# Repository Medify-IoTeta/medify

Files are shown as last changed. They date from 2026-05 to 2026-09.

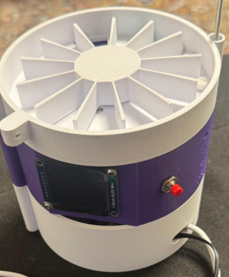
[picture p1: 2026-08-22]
docs/PillBox1.png

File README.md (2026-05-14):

# Medify — Smart Pill Box System

Medify is a smart medication intake system designed to help users manage and monitor their daily medication schedule. A physical smart pill box releases medication at scheduled times, while a mobile app handles reminders, intake confirmation, and caregiver monitoring.

## System Overview

```
Smart Pill Box (Arduino) ──WiFi──► Backend (Spring Boot) ◄──REST──  Mobile App (Flutter)
                                          │
                                    PostgreSQL 15
```

### Components

| Component | Technology | Location |
|---|---|---|
| Mobile App | Flutter / Dart | `medify_app/` |
| Backend Server | Java 21 / Spring Boot 3.4 | `medify-backend/` |
| Smart Pill Box | C++ / Arduino | `medify-embedded/` |
| Documentation | | `docs/` |

## Key Features

- **Scheduled reminders** — notifications sent at Morning / Noon / Evening intake windows
- **Intake confirmation** — user approves via app, device physically releases medication
- **Intake tracking** — statuses: Pending, Approved, Taken, Missed, Skipped, Postponed
- **Caregiver monitoring** — family members can view intake history and receive missed-dose alerts
- **Simple UI** — designed for elderly and passive users

## Getting Started

### Prerequisites

- Java 21
- Maven
- Docker (for the database)
- Flutter SDK

### Run Locally

```bash
# 1. Start the database
cd medify-backend
docker-compose up -d

# 2. Start the backend
mvn spring-boot:run -pl app

# 3. Start the Flutter app (in a separate terminal)
cd medify_app
flutter run
```

## Documentation

- Backend: [`medify-backend/README.md`](medify-backend/README.md)
- Mobile App: [`medify_app/README.md`](medify_app/README.md)
- Product requirements: [`docs/project-overview.docx`](docs/project-overview.docx)

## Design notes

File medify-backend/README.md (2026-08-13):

# Medify Backend

Spring Boot backend server for the Medify smart pill box system. Handles medication schedules, intake tracking, notifications, and caregiver monitoring.

## Tech Stack

- Java 21
- Spring Boot 3.4.0
- PostgreSQL 15
- Flyway (database migrations)
- JPA / Hibernate
- Lombok
- Docker

## Architecture

Hexagonal (ports-and-adapters) Maven multi-module project:

```
app → api → domain
      ↓
     data → domain
```

| Module | Responsibility |
|---|---|
| `domain` | Business logic, models, port interfaces, schedulers |
| `data` | JPA repositories, Flyway migrations |
| `api` | REST controllers, services, NotificationAdapter |
| `app` | Spring Boot entry point |

## Getting Started

### Prerequisites

- Docker (recommended — runs Postgres + backend together)
- Java 21 and Maven (only needed if running the backend outside Docker)

### Run everything with Docker (recommended)

```bash
# Place your Firebase service-account key at medify-backend/secrets/firebase-service-account.json
# (git-ignored — ask a teammate or generate one in the Firebase console)

docker compose up --build
```

This starts Postgres and the backend together, wires the backend to Postgres via the
`postgres` service hostname, persists Postgres data in the `medify_data` volume, and
exposes the backend on `http://localhost:8080`. Config is driven by environment
variables — see `.env.example`. Health check: `GET /actuator/health`.

### Run the backend outside Docker

```bash
# Start only the database
docker compose up -d postgres

# Point the app at it and run
export DB_HOST=localhost
export FIREBASE_CREDENTIALS_PATH=./secrets/firebase-service-account.json
mvn spring-boot:run -pl app
```

The server starts on `http://localhost:8080`.

## API Reference

| Method | Endpoint | Description |
|---|---|---|
| GET | `/api/notification` | Poll for a pending notification |
| POST | `/api/notification` | Send user response (confirm / snooze / skip) |
| GET | `/api/medicines` | List all medicines |
| POST | `/api/medicines` | Register a new medicine |
| GET | `/api/intakes/today` | Today's intakes |
| PATCH | `/api/intakes/{id}/approve` | User approved intake |
| PATCH | `/api/intakes/{id}/released` | Device confirmed compartment emptied → TAKEN |
| PATCH | `/api/intakes/{id}/skip` | User skipped intake |
| PATCH | `/api/intakes/{id}/postpone` | User postponed intake |
| PATCH | `/api/intakes/{id}/missed` | Mark intake as MISSED |
| GET | `/api/notifications-log` | Notification history (`?userId=`) |

## Notification Flow

1. Scheduler fires at scheduled time (currently demo times: 22:05 / 22:10 / 22:30)
2. Creates one `Intake` record per timing window
3. Sends notification: `"Time to take your morning medicines"`
4. Frontend polls `GET /api/notification` and shows a dialog
5. User confirms → `approve` → device dispenses → `released` → intake marked as TAKEN

> To switch to production times (08:00 / 13:00 / 20:00), update the `@Scheduled` cron expressions in `ReminderScheduler.java`.

## Database

PostgreSQL 15 via Docker. Defaults below apply when no `.env` is provided; override any
of them with `DB_HOST` / `DB_PORT` / `DB_NAME` / `DB_USERNAME` / `DB_PASSWORD`.

| Setting | Default |
|---|---|
| Database | `medify` |
| User | `medify_user` |
| Password | `medify_pass` |
| Port | `5432` |

Schema is managed by Flyway. Migrations are in `data/src/main/resources/db/migration/`.

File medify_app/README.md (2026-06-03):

# Medify App

Flutter mobile application for the Medify smart pill box system. Serves both patients and caregivers.

## Tech Stack

- Flutter / Dart
- HTTP client (`package:http`)
- Google Fonts
- UUID

## Getting Started

### Prerequisites

- Flutter SDK
- Backend server running on `localhost:8080` (see [`medify-backend`](../medify-backend/README.md))

### Run

```bash
flutter run
```

## Screens

### Home Screen (Patient)
- Medication schedule grouped by intake window: Morning / Noon / Evening
- Each window is expandable to show medicines with dosage and instructions
- Progress indicator: how many windows completed today
- Notification polling every 3 seconds — shows a reminder dialog when it's time to take medication
- Dialog includes option to expand and see which medicines are in the window

### Caregiver Screen
- Summary card: windows completed today out of total scheduled
- Full medication schedule (always visible, grouped by window)
- Today's intake status per window (TAKEN / MISSED / PENDING / POSTPONED)
- Missed alerts log

### Register Screen
- Add a new medicine with name, dosage, timing window, and intake instructions

## Project Structure

```
lib/
├── main.dart
├── screens/
│   ├── home_screen.dart
│   ├── caregiver_screen.dart
│   └── register_screen.dart
├── models/
│   └── medicine.dart
├── services/
│   └── api_service.dart
├── widgets/
│   ├── medication_card.dart
│   ├── app_sidebar.dart
│   └── progress_ring.dart
└── theme/
    └── app_theme.dart
```

## Configuration

Backend URL is set in `lib/services/api_service.dart`:

```dart
// Switch between these two depending on target:
//static const String baseUrl = 'http://localhost:8080'; // browser / emulator
static const String baseUrl = 'http://192.168.7.17:8080'; // Android device (active)
static const String embeddedBaseUrl = 'http://192.168.7.18'; // pill box device
```

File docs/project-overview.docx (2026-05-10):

Project: Medify – smart pill box

Description:

The Medify system is a smart medication intake solution designed to manage and monitor medication intake for users who take multiple medications on a predefined schedule.

At scheduled intake times, the system automatically releases the medications into a dedicated intake compartment, based on user approval.
Medication intake is confirmed only after the intake compartment is emptied.

The system records intake times, provides reminders and alerts through a mobile application, and allows remote monitoring by family members or caregivers.

The goal of the system is to reduce medication intake errors while providing a simple, reliable, and intuitive user experience, suitable also for passive users.

Use cases:

1. Medication guidance and intake monitoring:

A user wants to know when medication should be taken and to track whether it was taken.

When it is time to take medication, the system sends a reminder through the mobile application.

After the user approves the intake, the system automatically releases the medication into a dedicated intake compartment.

The system records the intake time only after the intake compartment is emptied and updates the medication status in the application.

2. Intake confirmation and handling of incomplete intake:

A user may not complete the medication intake after medications were released.
The system monitors whether the intake compartment was emptied within a predefined time window.

If the intake compartment is not emptied, the system marks the intake as incomplete and sends a notification to the user.
When required, the system also updates family members or caregivers about the incomplete intake.

3. Monitoring by family members or caregivers:

A family member or caregiver wants to monitor the medication intake of a patient who has difficulty managing it independently.
The application allows viewing the medication status and receiving alerts for taken, missed, postponed, skipped, or incomplete intakes.

Requirements:

1. Medication dispensing and intake confirmation:

The system should dispense medication at the scheduled time by releasing it into a dedicated intake compartment, and confirm the intake only after the intake compartment is emptied.

2. User guidance:

The system should notify the user when it is time to take medication, according to the predefined schedule, through a mobile notification and an on-device screen indication.

3. Intake time recording:

The system should record medication intake times and present the status of each intake in the mobile application, based on confirmed intake after the intake compartment is emptied.

4. Alerts and updates:

The system should notify the user in cases of deviations from the medication intake process, such as missed, skipped, or incomplete intakes, and allow updates to be shared with family members or caregivers when required.

5. Remote monitoring:

The application should allow family members or caregivers to monitor the user’s medication intake status.

6. Ease of use:

The application should be designed to be simple and intuitive, with a clear interface suitable for users who have difficulty using complex applications, such as elderly users.

7. Reliability:

The system should operate reliably and provide consistent and accurate information about medication intake.

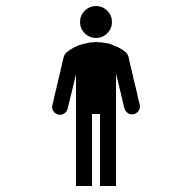
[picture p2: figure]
Man with solid fill
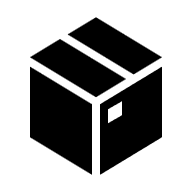
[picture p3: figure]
Box with solid fill
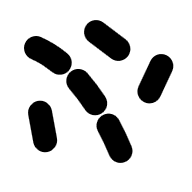
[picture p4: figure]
Germ with solid fill
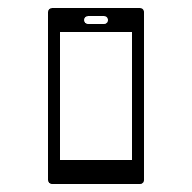
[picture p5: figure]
Smart Phone with solid fill
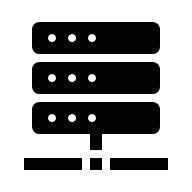
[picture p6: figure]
Server with solid fill
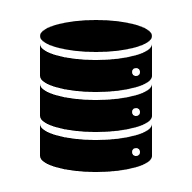
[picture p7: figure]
Database with solid fill

System Architecture:

User

Smart pill box

Mobile application

Backend server

Database

WIFI

Internet (REST API)

Modules:

1. Smart Pill Box Module (Device)

The Smart Pill Box module is responsible for the physical execution of medication intake and for reliable reporting of intake status to the system.

- Medication Release Mechanism Releases medication into the intake compartment according to the predefined schedule, after user confirmation either via a physical button press on the device or through the mobile application during the intake window.
- Intake Compartment Monitoring Monitors the intake compartment to detect whether the medication was taken, based on the compartment state (empty / not empty).
- Local User Indication Provides on-device guidance to the user using local indicators such as LEDs or a display, signaling when medication should be taken.
- Network Communication Communicates with the backend server over Wi-Fi using a REST API to report intake status and receive configuration updates.
- Autonomous Operation Operates independently of the mobile application and continues functioning even when the user’s phone is not nearby.

2. Mobile Application Module

The Mobile Application module serves as the primary user interface for patients, family members, and caregivers, enabling monitoring, notifications, and interaction with the system.

- Medication Schedule Visualization Displays the medication schedule and the status of each intake window, including taken, missed, postponed, or incomplete intakes.
- Notifications and Reminders Sends reminders to the user when an intake window begins and alerts in cases of deviations from the expected intake process.
- Intake Status Monitoring Retrieves intake status updates from the backend server and presents real-time or historical intake information.
- Intake Postponement (Snooze) Allows the user to postpone an intake window and receive a follow-up reminder after a predefined delay.
- Caregiver and Family View Enables authorized family members or caregivers to monitor medication intake status and receive relevant alerts.
- User Interaction Interface Provides a simple and intuitive interface designed to be accessible for elderly or passive users.

3. Backend Server Module

The Backend Server module functions as the central logic layer of the system, coordinating communication between the device, the mobile application, and the database.

- User and Role Management Manages users, including patients and authorized caregivers, and their associated permissions.
- Medication Schedule Management Stores and manages medication schedules and intake windows for each user.
- Intake Status Processing Receives intake status updates from the smart pill box, processes them, and determines the final intake state.
- Postponement Logic (Snooze Handling) Handles postponed intake windows and triggers follow-up reminders according to system rules.
- Notification and Alert Logic Determines when notifications should be sent to users and caregivers based on intake events or deviations.
- API Interface Exposes a REST API used by both the smart pill box and the mobile application for secure data exchange.

4. Database Module

The Database module is responsible for persistent and reliable storage of all system data, enabling long term tracking and monitoring.

- User Data Storage Stores user profiles, roles, and caregiver relationships.
- Medication and Schedule Storage Maintains information about medications and their associated intake schedules.
- Intake History Records Stores historical records of medication intake, including timestamps and intake status.
- Alert and Notification Logs Records notifications and alerts sent by the system for tracking and system monitoring purposes.
- Data Consistency and Reliability Ensures data integrity and supports recovery in case of system failures.

Technology Stack:

Smart Pill Box Device: Language: C++, Framework: Arduino.

Mobile: Language: Dart, Framework: Flutter.

Backend: Language: Java, Framework: Spring Boot.

Database: Language: SQL, Technology: PostgreSQL

API

Authentication Service:

- Endpoint: POST /auth/register Description: Creates a new user account (PATIENT or CAREGIVER). Request JSON: username, email, phone, password, type Response JSON: id, username, email, phone, type
- Endpoint: POST /auth/login

Description: Authenticates user credentials and returns an access token.

Request JSON: email, password

Response JSON: access_token, token_type, expires_in, user (id, username, email, phone, type)

- Endpoint: GET /users/me

Description: Returns the authenticated user profile information.

Request Headers: Authorization: Bearer <access_token>

Response JSON: id, username, email, phone, type

- Endpoint: PATCH /users/me/password

Description: Updates the authenticated user's password.

Request JSON: current_password, new_password

Response JSON: success

Caregiver Links API

- Endpoint: POST /caregiver-links

Description: Creates a caregiver link between a patient and a caregiver.

Request JSON: patient_id, caregiver_id, receive_alerts

Response JSON: patient_id, caregiver_id, receive_alerts

- Endpoint: GET /caregiver-links Description: Returns all caregiver links associated with the authenticated user (as patient or caregiver). Request Headers: Authorization: Bearer <access_token> Response JSON: items (array of: patient_id, caregiver_id, receive_alerts)
- Endpoint: PATCH /caregiver-links Description: Updates alert preference for an existing caregiver link. Request JSON: patient_id, caregiver_id, receive_alerts Response JSON: patient_id, caregiver_id, receive_alerts
- Endpoint: DELETE /caregiver-links Description: Removes an existing caregiver link between a patient and a caregiver. Request JSON: patient_id, caregiver_id Response JSON: success

Devices API

- Endpoint: POST /devices Description: Registers a new smart pill box device and assigns it to a patient. Request JSON: user_id, device_serial, device_name (optional)

Response JSON: id, user_id, device_serial, device_name, is_active, last_seen_time

- Endpoint: GET /devices Description: Returns all devices associated with the authenticated patient. Request Headers: Authorization: Bearer <access_token> Response JSON: items (array of: id, device_serial, device_name, is_active, last_seen_time)
- Endpoint: GET /devices/{id} Description: Returns detailed information about a specific device. Response JSON: id, user_id, device_serial, device_name, is_active, last_seen_time
- Endpoint: PATCH /devices/{id} Description: Updates device name or activation status. Request JSON: device_name (optional), is_active (optional) Response JSON: id, device_name, is_active
- Endpoint: PATCH /devices/{id}/heartbeat Description: Updates the device last communication time to indicate that the device is online. Request JSON: (empty) Response JSON: id, last_seen_time

Medications API

- Endpoint: POST /medications Description: Creates a new medication for the authenticated patient, including optional pre-intake reminder rules. Request Headers: Authorization: Bearer <access_token> Request JSON: name, description (optional), pre_intake_notice_minutes (optional), pre_intake_notice_text (optional), is_active Response JSON: id, user_id, name, description, pre_intake_notice_minutes, pre_intake_notice_text, is_active
- Endpoint: GET /medications

Description: Returns all medications for the authenticated patient.

Request Headers: Authorization: Bearer <access_token>

Response JSON: items (array of: id, name, description, pre_intake_notice_minutes, pre_intake_notice_text, is_active)

- Endpoint: GET /medications/{id} Description: Returns a specific medication by id. Request Headers: Authorization: Bearer <access_token> Response JSON: id, user_id, name, description, pre_intake_notice_minutes, pre_intake_notice_text, is_active
- Endpoint: PATCH /medications/{id} Description: Updates medication fields and reminder rules for the authenticated patient. Request Headers: Authorization: Bearer <access_token> Request JSON: name (optional), description (optional), pre_intake_notice_minutes (optional), pre_intake_notice_text (optional), is_active (optional) Response JSON: id, user_id, name, description, pre_intake_notice_minutes, pre_intake_notice_text, is_active
- Endpoint: DELETE /medications/{id} Description: Deletes a medication by id for the authenticated patient. Request Headers: Authorization: Bearer <access_token> Response JSON: success

Intakes API

- Endpoint: GET /intakes Description: Returns intake windows for the authenticated patient within a requested time range. Request Headers: Authorization: Bearer <access_token> Request Query Params: from (datetime), to (datetime) Response JSON: items (array of: id, device_id, window_start_time, window_end_time, approved_time, released_time, emptied_time, status)
- Endpoint: GET /intakes/{id} Description: Returns a specific intake window occurrence by id. Request Headers: Authorization: Bearer <access_token> Response JSON: id, user_id, device_id, window_start_time, window_end_time, approved_time, released_time, emptied_time, status
- Endpoint: GET /intakes/today Description: Returns all intake windows for the authenticated patient for the current day. Request Headers: Authorization: Bearer <access_token> Response JSON: items (array of: id, device_id, window_start_time, window_end_time, approved_time, released_time, emptied_time, status)
- Endpoint: POST /intakes Description: Creates an intake window occurrence for a patient and device. Request JSON: user_id, device_id, window_start_time, window_end_time Response JSON: id, user_id, device_id, window_start_time, window_end_time, status
- Endpoint: PATCH /intakes/{id}/approve Description: Approves medication release for the intake window and stores the approval time. Request JSON: (empty) Response JSON: id, approved_time, status
- Endpoint: PATCH /intakes/{id}/released Description: Marks that medication was released into the intake compartment for this intake window. Request JSON: (empty) Response JSON: id, released_time, status
- Endpoint: PATCH /intakes/{id}/emptied Description: Marks that the intake compartment was detected as emptied and finalizes the intake status as TAKEN. Request JSON: (empty) Response JSON: id, emptied_time, status
- Endpoint: PATCH /intakes/{id}/skip Description: Skips the intake window and finalizes the status as SKIPPED. Request JSON: (empty) Response JSON: id, status
- Endpoint: PATCH /intakes/{id}/postpone Description: Postpones the intake window and finalizes the status as POSTPONED. Request JSON: (empty) Response JSON: id, status
- Endpoint: PATCH /intakes/{id}/missed Description: Marks the intake window as MISSED. Request Headers: Authorization: Bearer <access_token> Request JSON: (empty) Response JSON: id, status
- Endpoint: PATCH /intakes/{id}/incomplete

Description: Marks the intake window as INCOMPLETE.

Request Headers: Authorization: Bearer <access_token>

Request JSON: (empty)

Response JSON: id, status

Notifications Log API

- Endpoint: GET /notifications-log Description: Returns notification history for the authenticated user (patient or caregiver) within a requested time range. Request Headers: Authorization: Bearer <access_token> Request Query Params: from (datetime), to (datetime) Response JSON: items (array of: id, recipient_user_id, intake_id (nullable), type, message, sent_time, delivery_status (nullable))

DB Tables:

Users:

Purpose:
Stores all system users, including patients and caregivers, along with their identification and authentication details.

Columns:

- id (PK): Unique identifier for each user in the system.
- Username: Display name of the user.
- Email: User email address, used for authentication and notifications.
- Phone: User phone number, used for alerts and communication.
- Password_hash: Hashed password used for secure user authentication.
- Type: Defines the user role in the system (PATIENT or CAREGIVER).

Caregiver links:

Purpose:
Defines the association between patients and their caregivers or family members for monitoring and alerting purposes.

Columns:

- patient_id (FK → users.id) References the user who is the patient being monitored.
- caregiver_id (FK → users.id) References the user who acts as a caregiver or family member.
- receive_alerts Indicates whether the caregiver receives notifications about the patient’s medication intake status.

Intakes:

Purpose:
Stores each medication intake window occurrence and its final status, based on whether the intake compartment was emptied during the allowed time window.

This table represents the actual intake events performed by the user and is used for tracking, monitoring, and notifications.

Columns:

- id (PK): Unique identifier for each intake window occurrence, generated by the database.
- user_id (FK → users.id): References the patient associated with this intake.
- device_id (FK → devices.id): References the smart pill box device that handled the intake.
- window_start_time: Start time of the intake window.
- window_end_time: End time of the intake window.
- approved_time (nullable): Time when the user approved the medication release (via device button or mobile application).
- released_time (nullable): Time when the medication was released into the intake compartment.
- emptied_time (nullable): Time when the intake compartment was detected as emptied.
- Status: Final status of the intake window (e.g., TAKEN, INCOMPLETE, MISSED, SKIPPED, POSTPONED).

Devices:

Purpose:
Stores smart pill box devices registered in the system and links each device to its associated patient, enabling monitoring and communication between the device and the backend server.

Columns:

- id (PK): Unique identifier for each device in the system, generated by the database.
- user_id (FK → users.id): References the patient who owns/uses the device.
- device_serial: Unique device identifier (e.g., printed serial number) used for registration and identification.
- device_name (nullable): Optional user-friendly name for the device (e.g., “Living Room Pill Box”).
- is_active: Indicates whether the device is currently active/assigned.
- last_seen_time (nullable): The last time the backend received a communication/status update from the device.

Medications:

Purpose:
Stores the list of medications defined for each patient, including basic medication information and medication-specific reminder rules.

This table is used for schedule creation and for displaying medication details and related reminders in the mobile application.

Columns:

- id (PK): Unique identifier for each medication in the database.
- user_id (FK → users.id): References the patient to whom the medication belongs.
- Name: Medication name, as displayed in the mobile application.
- Description (nullable): Optional notes or instructions related to the medication (e.g., “take after food”, “take with water”).
- Pre_intake_notice_minutes (nullable): Number of minutes before the intake time to notify the user with a medication-related reminder.
- Pre_intake_notice_text (nullable): Text content of the medication-related reminder to be shown to the user (e.g., “Eat a meal before taking this medication”).
- Is_active: Indicates whether the medication is currently active for the patient.

Notifications log:

Purpose:
Stores a history of notifications and alerts sent by the system to patients and caregivers.
This table is used for monitoring, debugging, and tracking deviations from the expected intake process.

Columns:

- Id (PK): Unique identifier for each notification log entry, generated by the database.
- Recipient_user_id (FK → users.id): References the user who received the notification (patient or caregiver).
- Intake_id (FK → intakes.id, nullable): References the related intake window occurrence, if the notification is associated with a specific intake.
- Type: Notification type (WINDOW_REMINDER, PRE_INTAKE_REMINDER, MISSED_INTAKE, INCOMPLETE_INTAKE).
- Message: The content of the notification sent to the user.
- Sent_time: Timestamp indicating when the notification was sent.
- Delivery_status (nullable): Indicates whether the notification was delivered successfully (SENT, FAILED).

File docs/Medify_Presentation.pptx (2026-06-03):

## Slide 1

Medify

Smart Medication Management System

By Netta Spivak & Roy Tomer

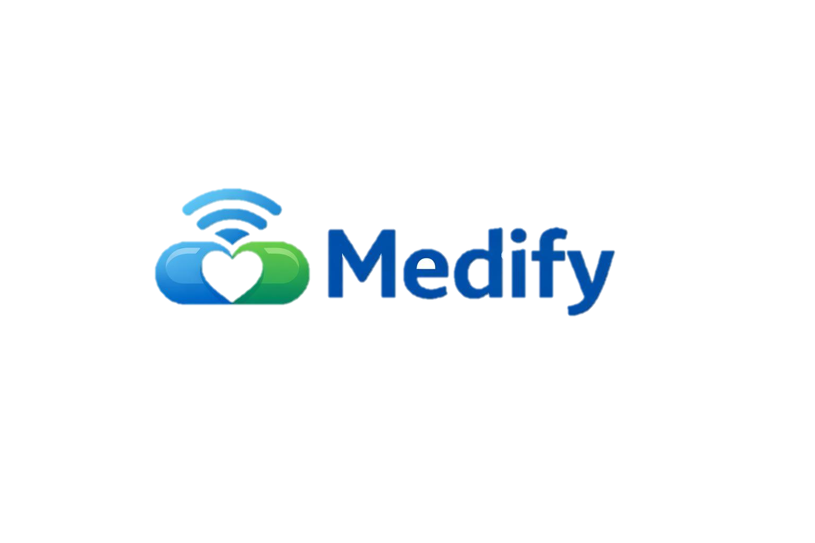
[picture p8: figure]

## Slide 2

The Problem

Why medication management is a critical challenge

- Patients taking multiple medications face high risk of missed or incorrect intake
- Passive solutions (pill organizers) provide no reminders or confirmation
- Complex apps are not suitable for elderly or cognitively impaired users
- Caregivers and family members have no visibility into daily intake compliance

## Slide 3

Our Solution

Bridging the gap between prescriptions and actual intake

From passive reminders to active medication management

Medify is a smart medication management system that combines a smart pill box with a mobile application to help patients take the right medication at the right time.
The system actively guides and monitors the medication intake process
from medication management, reminders and caregiver alerts to medication dispensing.

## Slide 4

Key Features

- Automatically dispenses medication at scheduled times after user approval.
- Using Sensor to identify when all of the medications were taken.

Smart Pill Box

- Real-time mobile reminders when an intake window opens.
- Intake approval via app or physical device button.
- Pre intake reminders.
- Caregiver view, for monitoring intake or missed intakes of the patient.

medication management

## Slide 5

System Architecture

Wi-Fi / REST

Smart Pill Box

Arduino / C++

Flutter App

Dart + Flutter

Wi-Fi / REST

REST API

Backend Server

Java + Spring Boot

Database

PostgreSQL 15

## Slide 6

Technology Stack

Choices and justifications

Backend

Java + Spring Boot

Java and Spring Boot provide a stable and proven environment for backend system development, with strong support for REST APIs, scheduling tasks, and database integration.

Frontend

Dart + Flutter

Flutter enables development of a single cross-platform application for both Android and iOS, while providing fast performance and a modern, responsive UI.

Hardware

Arduino / C++

Arduino and C++ provide a simple and accessible platform for embedded systems development, with extensive hardware library support and precise control over the device’s behavior.

Database

PostgreSQL

PostgreSQL provides reliable and consistent data management, while allowing easy schema management and smooth integration with Spring Boot.

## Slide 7

Domain — Smart Pill Box

Arduino / C++

Medication Release

Motor-driven mechanism releases medication into the intake compartment at scheduled times, after user approval

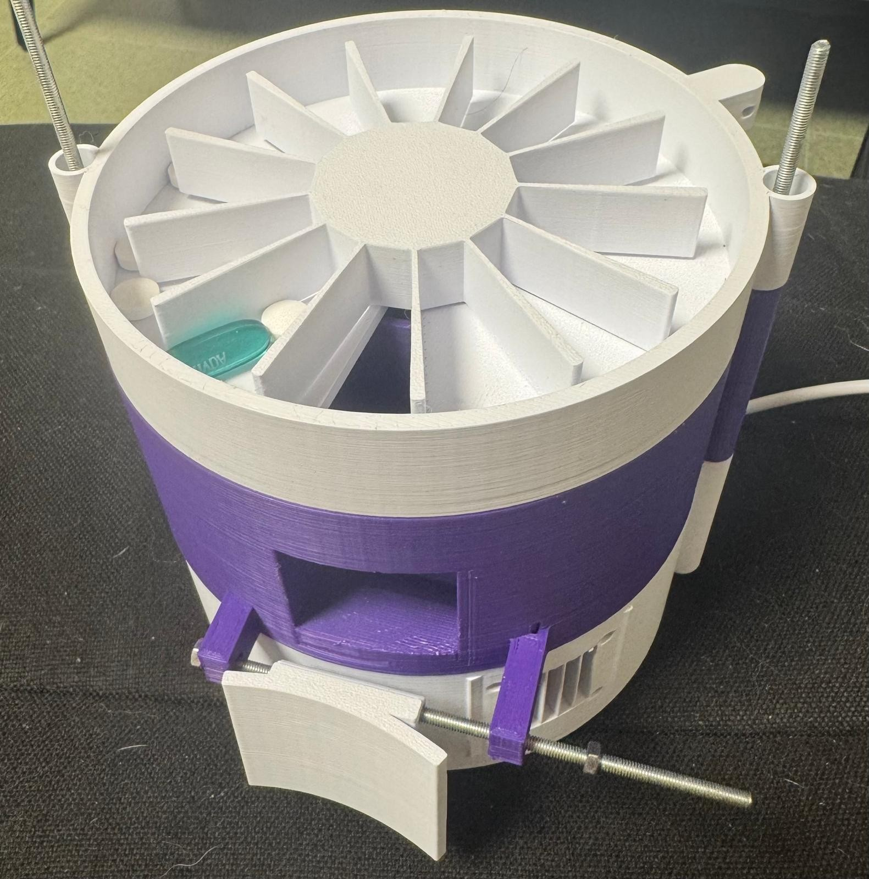
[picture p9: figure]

Compartment Monitoring

Sensor detects whether the intake compartment was emptied within the allowed time window

Medication Loading Guidance

LED indicators assist the user during medication setup by illuminating the correct compartments for each medication.

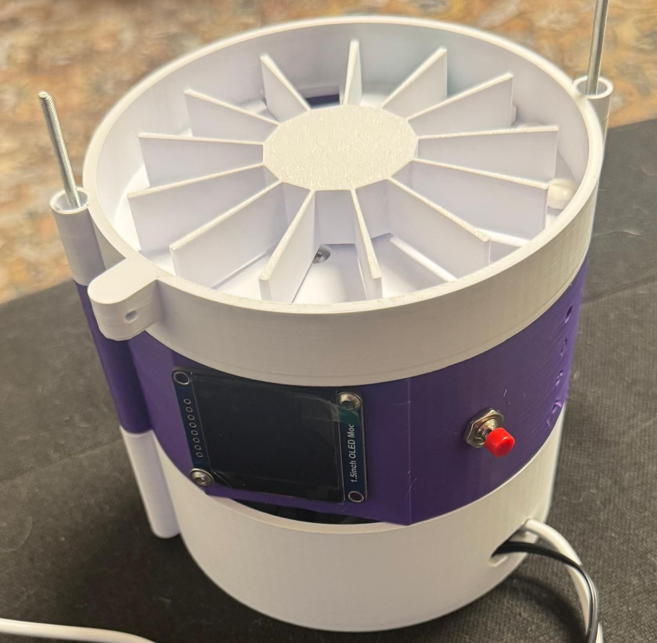
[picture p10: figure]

Autonomous Operation

Continues functioning independently even when the patient's phone is not nearby

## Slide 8

Domain — Mobile Application

Flutter + Dart

Medication Management

Users can manage their medications, define intake windows, and update their treatment routine directly through the app.

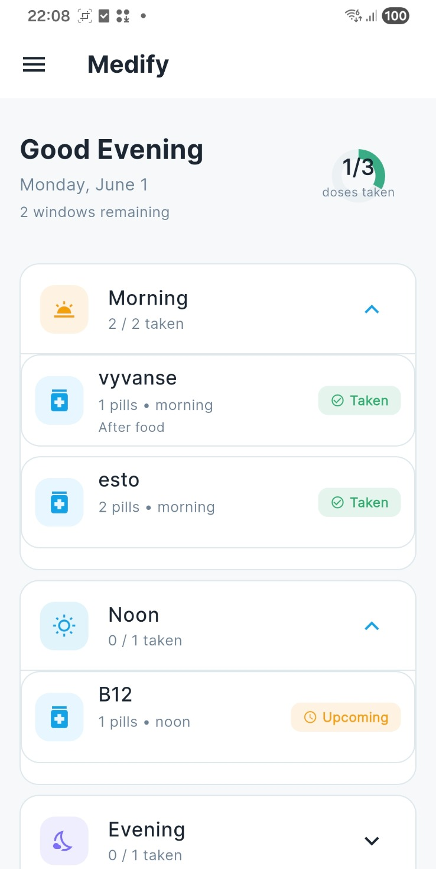
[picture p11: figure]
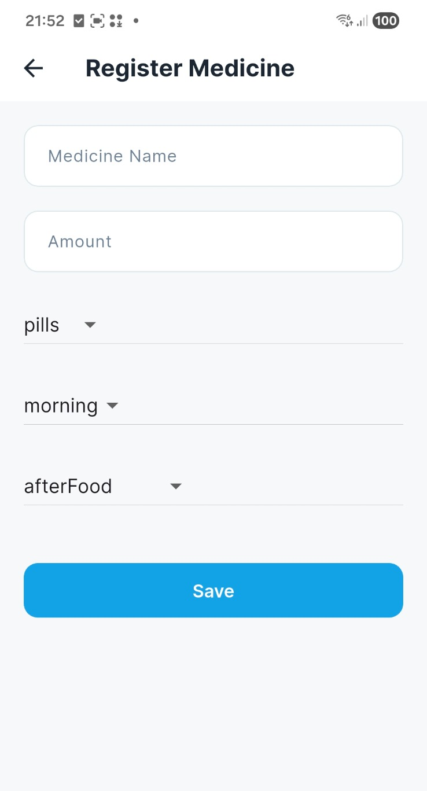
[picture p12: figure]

Accessible Experience

Simple UI designed to support elderly users.

Medication Setup

Guide users through the process of loading medications into the smart pill box.

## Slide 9

Domain — Mobile Application

Flutter + Dart

Notifications
& Reminders

Users receive reminders when an intake window opens, with the option to approve medication intake or snooze.

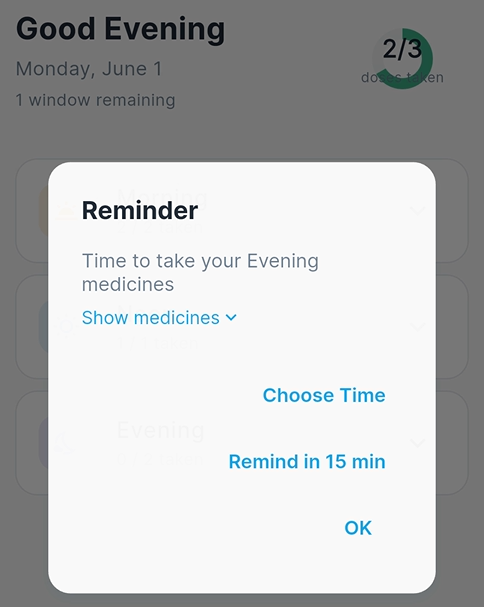
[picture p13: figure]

Caregiver View

Caregivers can monitor medication intake status in real time and receive alerts for missed or incomplete intakes.

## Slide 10

Domain — Backend Server

Java 21 · Spring Boot 3.4

Scheduling

Handles intake-related events based on predefined schedules.

Modules Structure

- app - Entry point.
- api - REST controllers, services.
- Domain - Business logic, schedulers, models.
- data - DB communication and access.

Intake Management

Manage the intake status lifecycle:
PENDING → APPROVED → TAKEN.

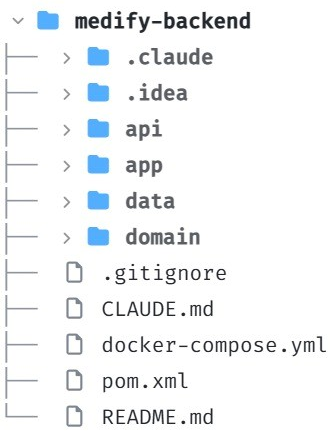
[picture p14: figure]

Data Management

Handles communication with the database.

Missed intake detection

Detects missed medication intake and sends alerts to caregivers.

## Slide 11

Domain — Database

PostgreSQL

users

User profiles, roles (PATIENT / CAREGIVER), authentication data

Medication name, timing window, dosage, pre-intake reminder rules

One record per timing window per day - tracks approval, release, and status

medications

intakes

caregiver_links

Patient-caregiver associations and alert preferences

notification_logs

History of all notifications and alerts sent by the system

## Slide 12

Current Project Status

Completed

- Patient app – register medications, schedule with intake window status, intake notification with approve or snooze options.
- Caregiver screen – intake schedule and daily status overview.
- Backend core - implement medication management, intake tracking, user and caregiver notifications and persistent DB storage.
- Automatic scheduling - Morning 08:00, Noon 13:00, Evening 20:00, and postpone an intake window.
- Arduino device - Wi-Fi communication, listen and response to API requests.
- Arduino device - app-controlled medication dispensing.
- PostgreSQL - database integration and schema management.

- Arduino device - detecting missed medication intake.
- Pill insertion flow - developing the process of inserting medications through the mobile application.
- Implementation of pre intake notifications.
- Multi-user support - extending the system to support multiple users and caregivers simultaneously.

Planned

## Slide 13

AI Usage in Development

- Lovable - used for visual planning and prototyping of the frontend screens before implementing them in Flutter.
- Claude Code - used for code generation, architecture discussions, debugging assistance, and project documentation.
- ChatGPT - used for document phrasing and assistance with planning the 3D printing components and OpenSCAD logic.

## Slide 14

System Demo

See Medify in action

▶

Video coming soon

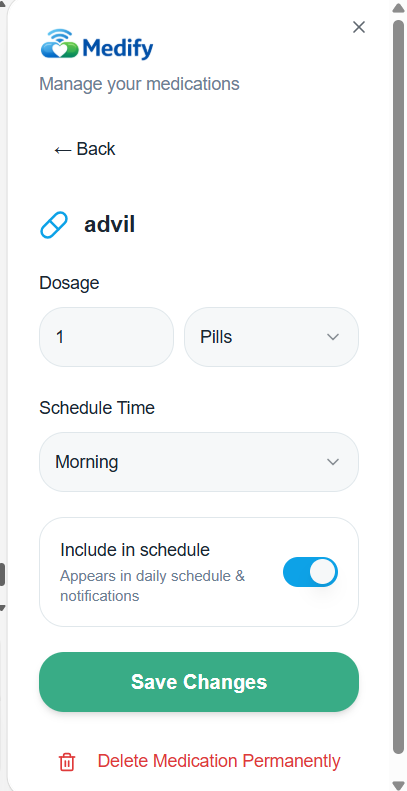
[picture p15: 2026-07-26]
docs/edit screen/Screenshot 2026-07-26 153617.png

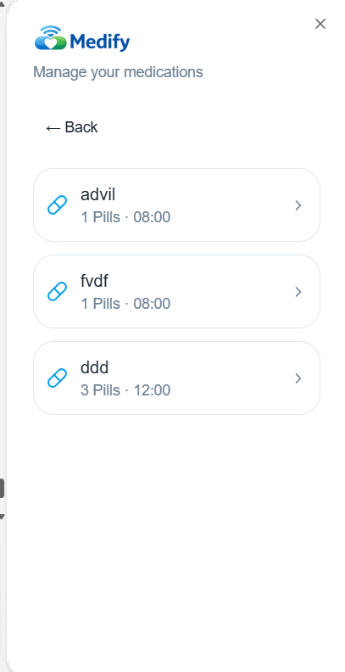
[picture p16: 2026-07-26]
docs/edit screen/Screenshot 2026-07-26 153655.png

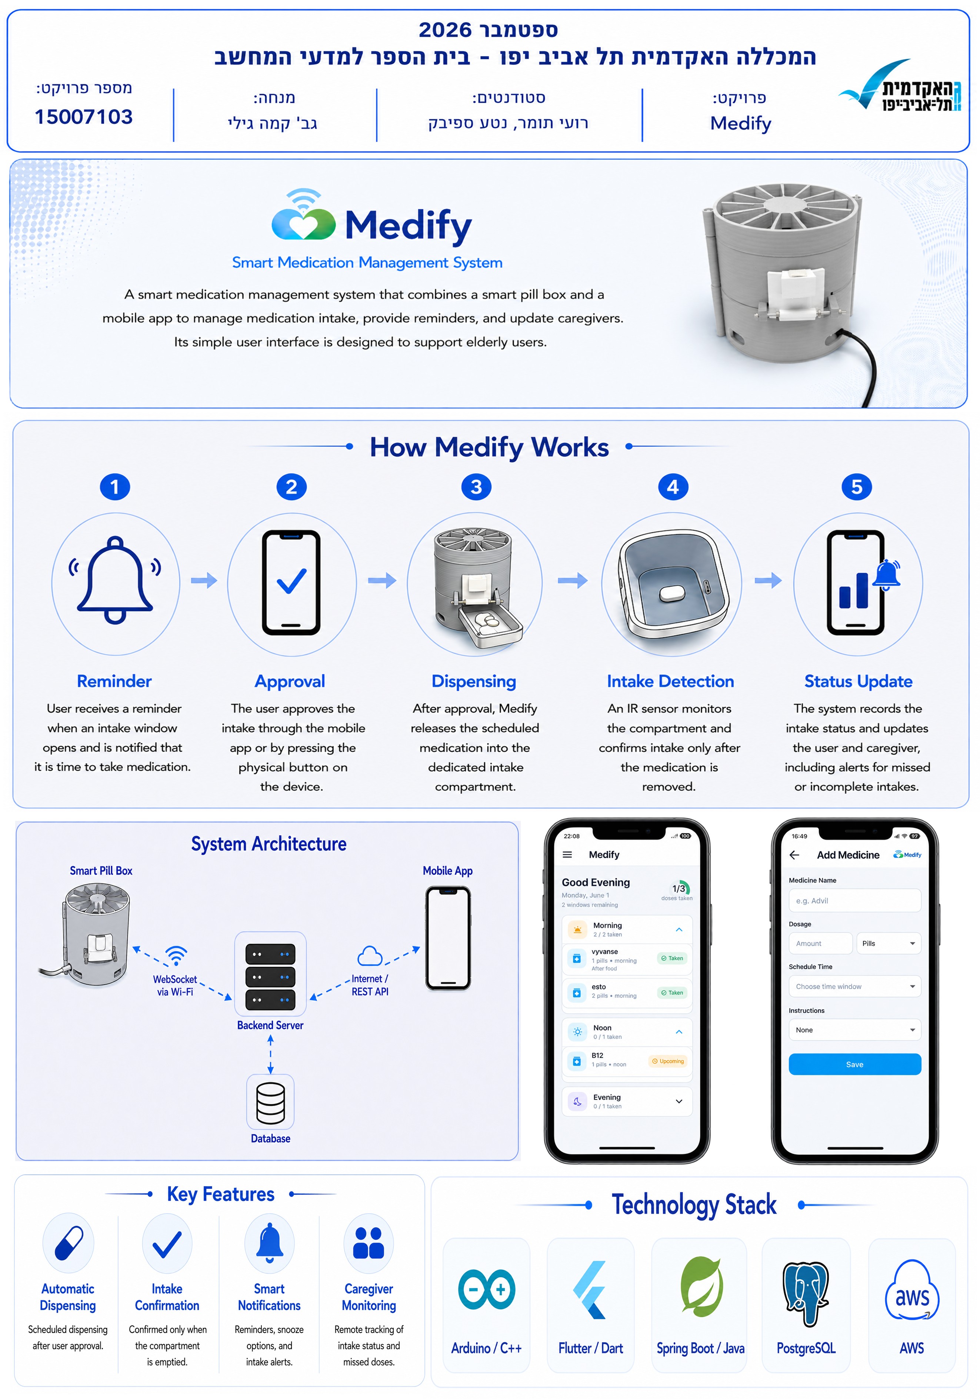
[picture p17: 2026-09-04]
docs/פוסטר.JPG

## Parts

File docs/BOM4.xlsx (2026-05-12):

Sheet: רכיבים
רכיבים
שם הרכיב | קישור | כמות | מחיר ליחידה | ספק | סטטוס | YES
Arduino Nano 33 IoT | קישור (https://www.4project.co.il/product/arduino-nano-33-iot-with-headers) | 1.00 | 150.30 | 4Project - 1 | בשימוש | YES
מטריצה - 400 נקודות | קישור (https://www.4project.co.il/product/breadboard-400-points-white) | 1.00 | 9.90 | 4Project - 1 | בשימוש | YES
מנוע צעד | קישור (https://www.4project.co.il/product/stepper-motor-28byj48-5v) | 1.00 | 14.80 | 4Project - 1 | בשימוש | YES
בקר למנוע צעד | קישור (https://hipertronics.co.il/product/%d7%9c%d7%95%d7%97-%d7%9c%d7%9e%d7%a0%d7%95%d7%a2-%d7%a6%d7%a2%d7%93-uln2003-%d7%9c%d7%90%d7%a8%d7%93%d7%95%d7%90%d7%99%d7%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) | 1.00 | 13.90 | היפרטרוניקס | בשימוש | YES
מסך OLED 0.91" | קישור (https://www.4project.co.il/product/oled-0.91inch-128x32-i2c-interface) | 1.00 | 37.80 | 4Project - 1 | טעות | YES
כפתור קטן | קישור (https://www.4project.co.il/product/panel-mount-button-red) | 1.00 | 2.90 | 4Project - 1 | לא הותקן | YES
מאוורר 25x25x10 | קישור (https://www.4project.co.il/product/540138) | 1.00 | 13.90 | 4Project - 1 | טעות | YES
כפתור גדול | קישור | 1.00 | 22.40 | 4Project - 1 | טעות | YES
ספק כוח 5V | קישור (https://www.4project.co.il/product/wall-adapter-power-supply-5v-2a) | 1.00 | 19.90 | 4Project - 1 | בשימוש | YES
רצועת לדים RGB | קישור (https://www.4project.co.il/product/addressable-rgb-60-led-strip-5v-1m-ws2812b) | 1.00 | 26.70 | 4Project - 3 | לא הותקן | YES
משדר IR קטן |  | 1.00 | 6.10 | 4Project - 1 | נהרס | YES
מקלט IR קטן |  | 1.00 | 6.10 | 4Project - 1 | נהרס | YES
מסך OLED 1.5" | קישור (https://www.4project.co.il/product/oled-1.5inch-128x128-i2c-spi-interface) | 1.00 | 78.20 | 4Project - 3 | לא הותקן | YES
מאוורר 10x30x30 |  | 1.00 | 13.70 | 4Project - 4 | לא הותקן | YES
מחבר שקע מתח | קישור (https://www.4project.co.il/product/334832) | 4.00 | 8.00 | 4Project - 1+ 2 | בשימוש | YES
IR Break Beam Sensor | קישור (https://www.dash.co.il/index.php?route=product/product&product_id=5375) | 1.00 | 80.00 | דאן אלקטרוניקה | לא הותקן | YES
 |  |  |  |  |  | NO
 |  |  |  |  |  | NO
 |  |  |  |  |  | NO
 |  |  |  |  |  | NO
 |  |  |  |  |  | NO
 |  |  |  |  |  | NO
 |  |  |  |  |  | NO
 |  |  |  |  |  | NO
 |  |  |  |  |  | NO
 |  |  |  |  |  | NO
 |  |  |  |  |  | NO
 |  |  |  |  |  | NO
 |  |  |  |  |  | NO
₪528.60 | סה"כ מחיר

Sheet: מוצרים נלווים
מוצרים נלווים
שם המוצר | לינק | שימוש | ספק | מחיר ליחידה | כמות יחידות | סטטוס | ספיירים | האם לחשב מחיר
נגד 100 אוהם | קישור (https://www.4project.co.il/product/resistor-100-ohm-5w-pth) |  | 4Project - 1 | 2.80 | 1.00 | לא בשימוש |  | YES
נגד 4.7 קילו אוהם |  |  | 4Project - 1 | 0.30 | 10.00 | לא בשימוש |  | YES
חוט זכר זכר 15 סנטימטר - 20 יחידות |  |  | 4Project - 1 | 18.80 | 2.00 | בשימוש חלקי |  | YES
חוט זכר נקבה 20 ס"מ - 40 יחידות |  |  | 4Project - 1 | 9.50 | 2.00 | בשימוש חלקי |  | YES
נגד 330 אוהם |  |  | 4Project - 2 | 0.30 | 10.00 | לא בשימוש |  | YES
קבל אלקטרוליטי 470 מיקרו |  |  | 4Project - 2 | 0.90 | 3.00 | לא בשימוש |  | YES
Esun PLA+ |  |  | ProMaker | 79.00 | 2.00 | בשימוש |  | YES
אום M3 |  |  | 4Project - 4 | 0.20 | 30.00 | בשימוש חלקי |  | YES
אום M3 ניילוק |  |  | 4Project - 4 | 0.25 | 10.00 | בשימוש חלקי |  | YES
דיסקית M3 שטוחה |  |  | 4Project - 4 | 0.07 | 40.00 | לא בשימוש |  | YES
בורג פיליפס ראש עגול mm10x2M |  |  | 4Project - 4 | 0.20 | 10.00 | לא בשימוש |  | YES
חוט פרימיום זכר זכר 12" - 10 יחידות | קישור (https://www.dash.co.il/index.php?product_id=1009387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) |  | דאן אלקטרוניקה | 32 | 1.00 | לא בשימוש |  | YES
חוט נקבה נקבה 6" - 20 יחידות | קישור (https://www.dash.co.il/index.php?route=product/product&product_id=1012796&search=JUMPER+WIRE+-+connected+6%22) |  | דאן אלקטרוניקה | 27.00 | 1.00 | לא בשימוש |  | YES
מוט הברגה M3 מגולוון 1 מטר | קישור (https://galboreg-shop.co.il/index.php?route=product/product&product_id=1049) |  | גלבורג | 7.08 | 5 | לא בשימוש |  | YES
אלן כפתור נירוסטה M3X10MM | קישור (https://galboreg-shop.co.il/index.php?route=product/product&product_id=19557) |  | גלבורג | 2.24 | 10 | לא בשימוש |  | YES
אלן כפתור נירוסטה M3X20MM | קישור (https://galboreg-shop.co.il/index.php?route=product/product&product_id=19562) |  | גלבורג | 3.54 | 10 | לא בשימוש |  | YES
 |  |  |  |  |  |  |  | NO
 |  |  |  |  |  |  |  | NO
 |  |  |  |  |  |  |  | NO
 |  |  |  |  |  |  |  | NO
 |  |  |  |  |  |  |  | NO
 |  |  |  |  |  |  |  | NO
 |  |  |  |  |  |  |  | NO
משלוח גלבורג |  |  | גלבורג | 38.00 | 1.00 |  |  | YES
אריזה ומשלוח 4Project |  |  | 4Project | 22.00 | 4.00 |  |  | YES
משלוח היפרטרוניקס |  |  | היפרטרוניקס | 50.00 | 1.00 |  |  | YES
משלוח ProMaker |  |  | ProMaker | 39.00 | 2.00 |  |  | YES
דמי טיפול גלבורג |  |  | גלבורג | 23.50 | 1.00 |  |  | YES
 |  |  |  |  |  |  |  | NO
₪669.10 | סה"כ מחיר

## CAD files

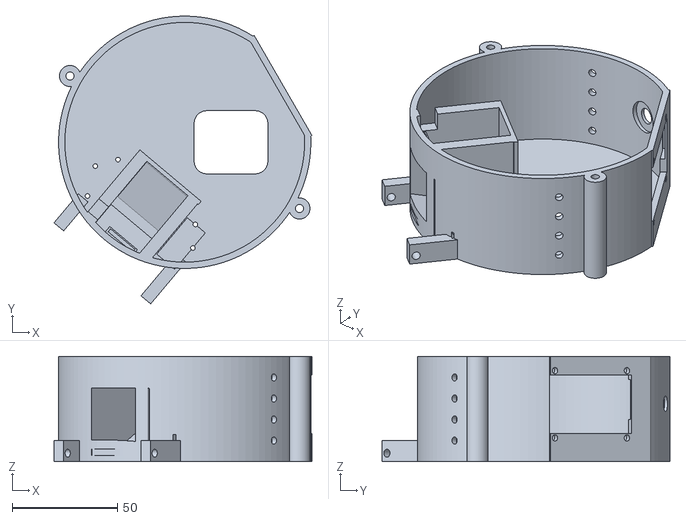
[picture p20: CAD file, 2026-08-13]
medify-embedded/Scad files/CurrentVersions/STL files/Floor1_6FINAL.stl
122.7 x 136.9 x 50.0

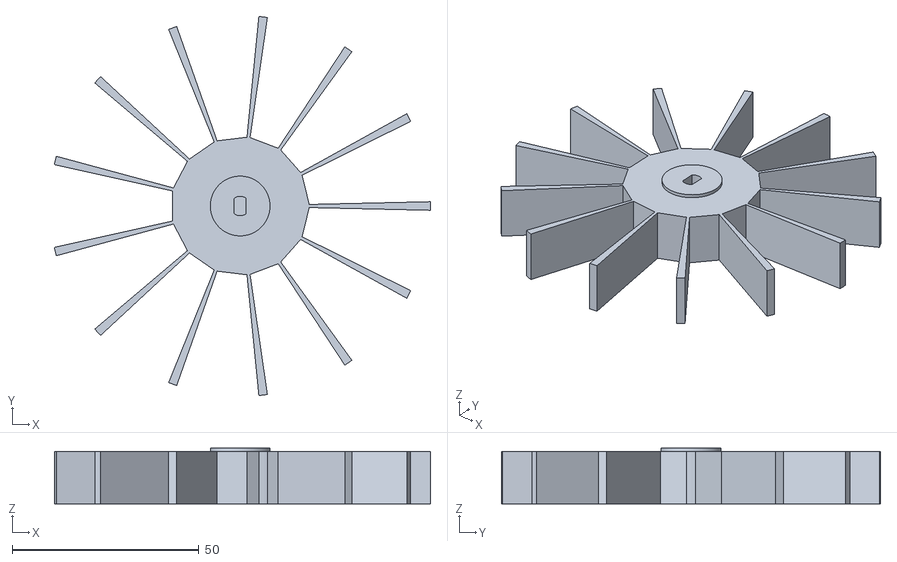
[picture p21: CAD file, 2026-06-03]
medify-embedded/Scad files/CurrentVersions/STL files/TempFourFloor2WindmillFINAL.stl
100.8 x 101.5 x 14.9

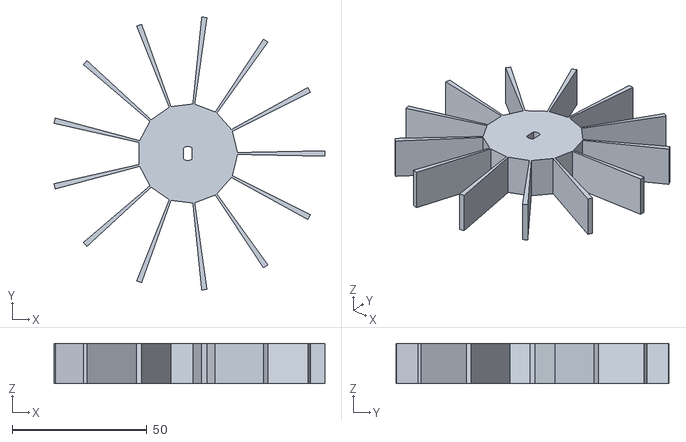
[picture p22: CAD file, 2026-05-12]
medify-embedded/Scad files/CurrentVersions/STL files/TempThreeFloor2WindmailFINAL.stl
100.7 x 101.4 x 15.0

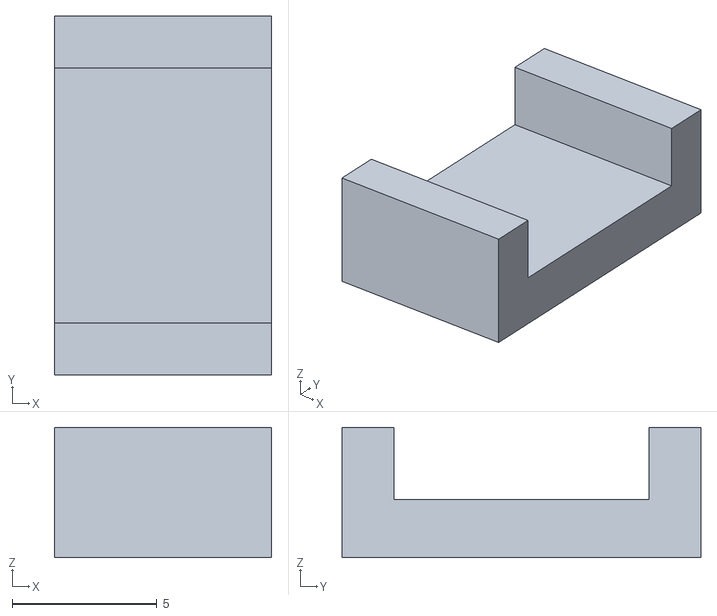
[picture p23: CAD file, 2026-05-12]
medify-embedded/Scad files/CurrentVersions/STL files/MagnetPocketCover3.stl
7.50 x 12.4 x 4.50

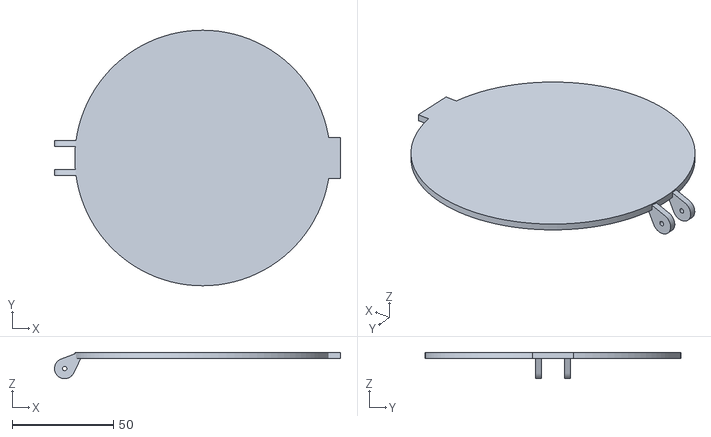
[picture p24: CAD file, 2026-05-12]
medify-embedded/Scad files/CurrentVersions/STL files/UpperCover.stl
141.0 x 126.0 x 13.0

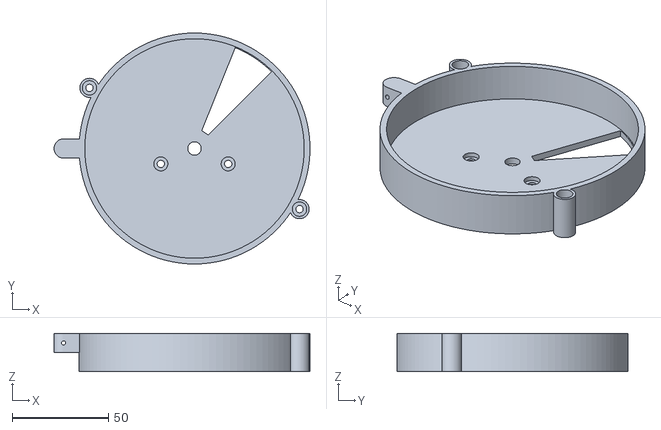
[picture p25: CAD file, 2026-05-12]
medify-embedded/Scad files/CurrentVersions/STL files/Floor2Base5FINALREAL.stl
133.0 x 120.0 x 20.0

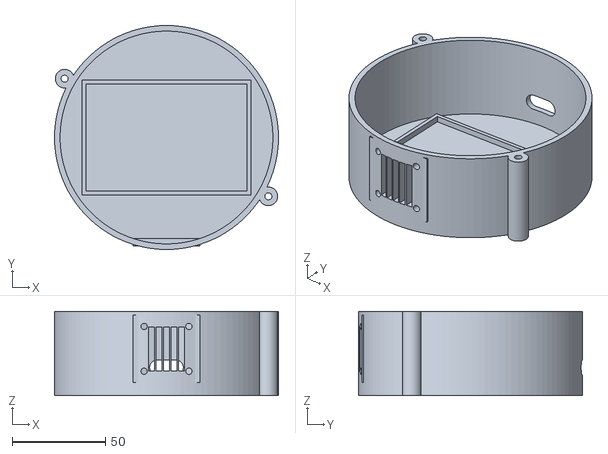
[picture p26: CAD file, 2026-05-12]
medify-embedded/Scad files/CurrentVersions/STL files/Floor0NEW.stl
120.0 x 120.0 x 45.0

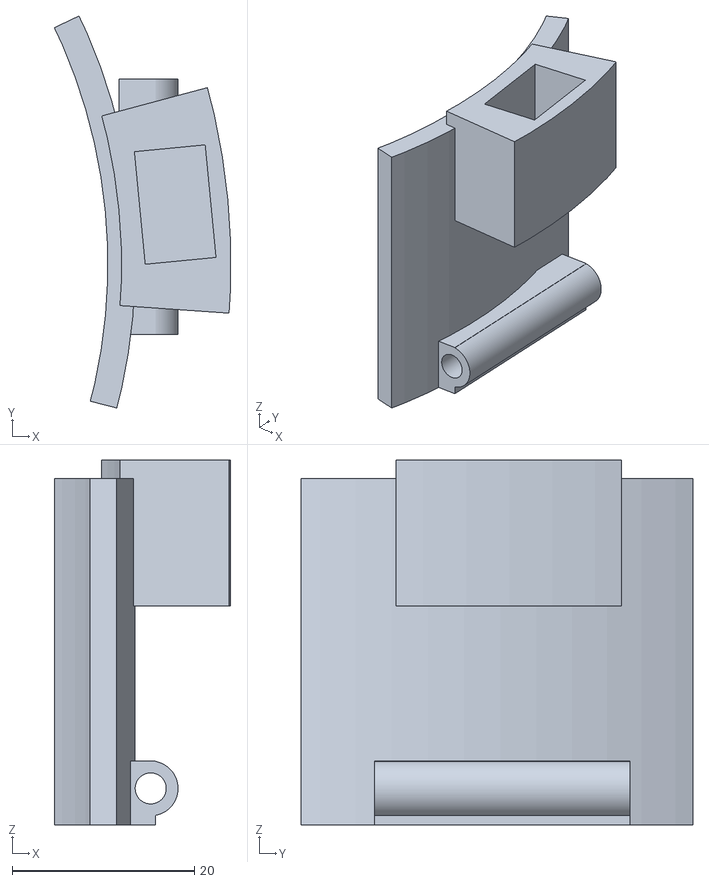
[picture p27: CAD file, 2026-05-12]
medify-embedded/Scad files/CurrentVersions/STL files/TempDoor.stl
19.3 x 43.0 x 40.0

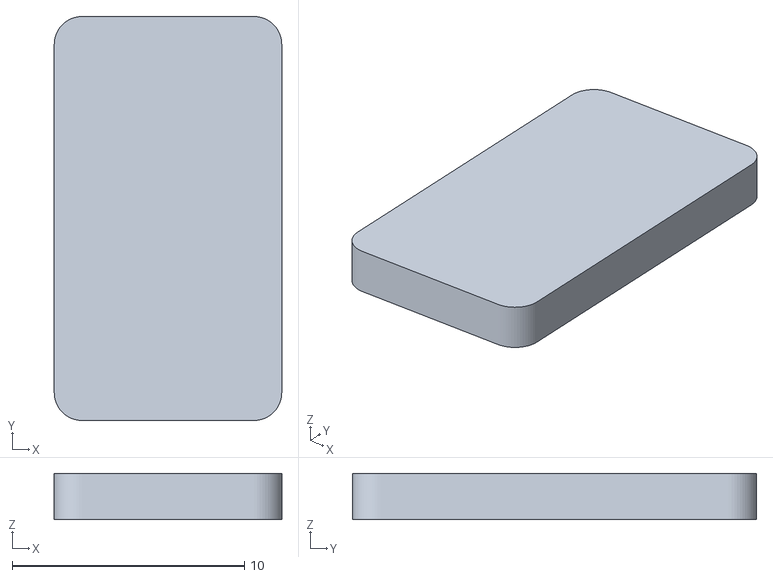
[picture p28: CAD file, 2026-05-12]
medify-embedded/Scad files/CurrentVersions/STL files/MagnetPocketCover1.stl
9.80 x 17.4 x 2.00

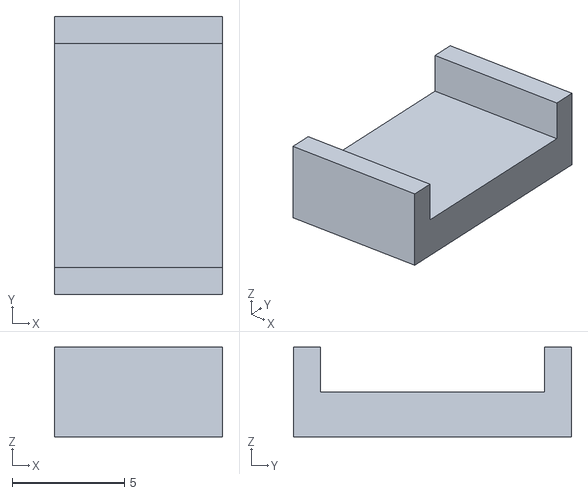
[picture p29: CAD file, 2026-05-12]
medify-embedded/Scad files/CurrentVersions/STL files/MagnetPocketCover2.stl
7.50 x 12.4 x 4.00

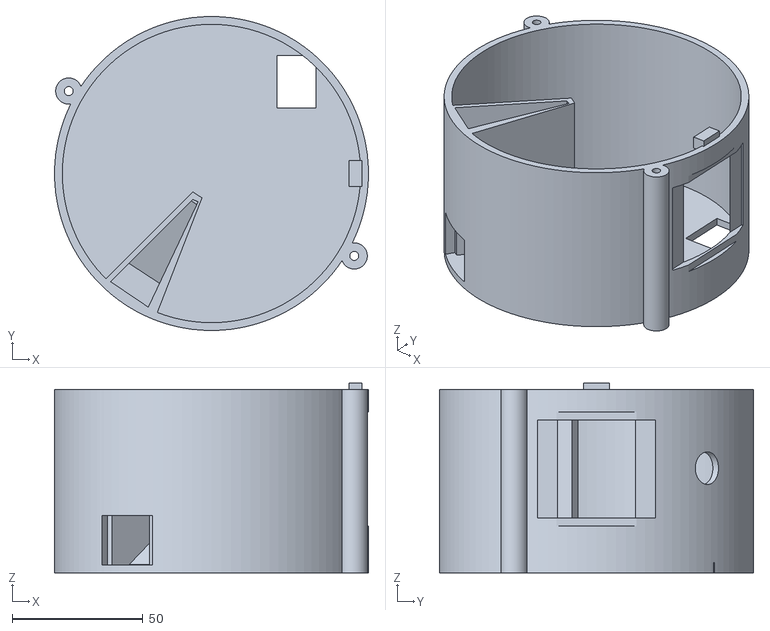
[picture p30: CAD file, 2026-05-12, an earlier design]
medify-embedded/Scad files/OldVersions/STL files/Floor1.stl
120.0 x 120.0 x 72.5

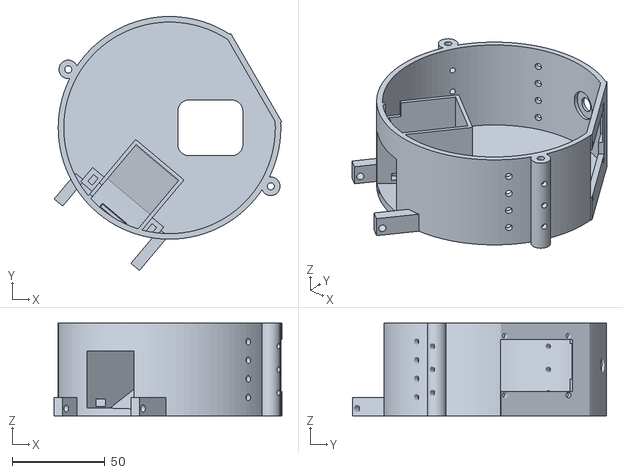
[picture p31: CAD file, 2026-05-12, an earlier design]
medify-embedded/Scad files/OldVersions/STL files/Floor1_3.stl
122.7 x 136.9 x 50.0

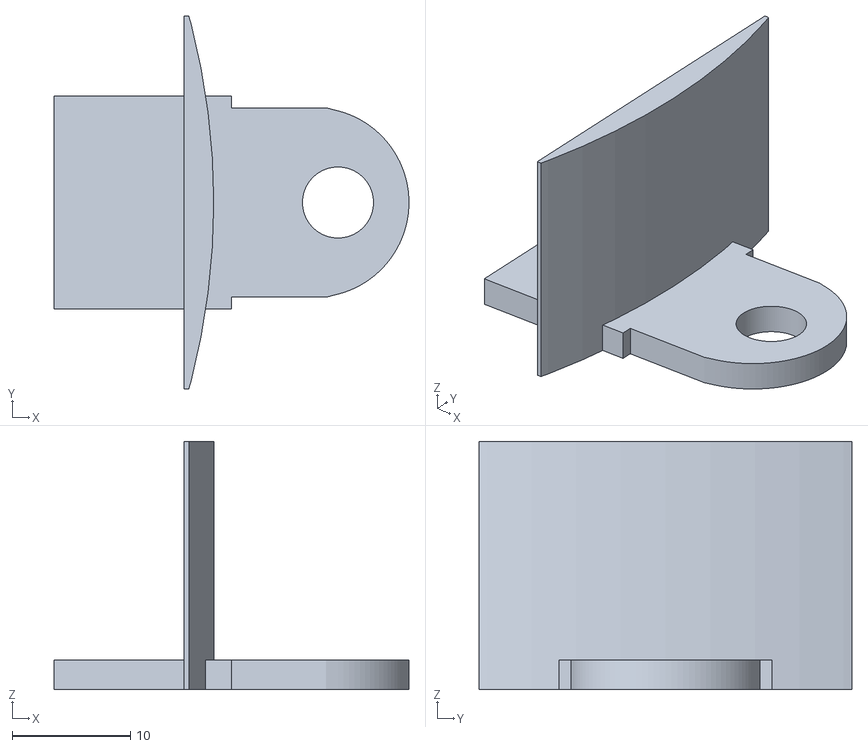
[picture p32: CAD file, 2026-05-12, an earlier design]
medify-embedded/Scad files/OldVersions/STL files/Drawer.stl
30.0 x 31.5 x 21.0

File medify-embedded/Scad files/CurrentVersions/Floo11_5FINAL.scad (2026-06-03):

// Medify - Floor 1: Middle Core (WITH THICKENED IR RECEIVER WALL + CIRCULAR RECESS)

module Floor1_Final_Design() {
    $fn = 100;
    chute_rotation = 50; 
    dia = 120; height = 50; 
    outer_wall = 3; inner_wall = 2; 
    chute_side_wall = 1.5;
    receiver_side_wall = 7;
    chute_floor_raise = 2;

    chute_w = 34; chute_d = 43.5; chute_y_pos = -7;  
    ir_x_pos = -dia/2 + 12; 
    ir_z_height = outer_wall + 4; 
    ir_win_w = 8.0; ir_win_h = 4.0; 

    ir_module_len = 20;
    ir_module_w = 10;
    ir_module_h = 9;
    ir_forward_shift = 0;
    ir_z_shift = 0.8;

    ir_center_x = ir_x_pos + ir_module_len/2 + ir_forward_shift;
    ir_center_z = ir_z_height + ir_z_shift;

    ir_led_x_offset = -5;
    ir_led_z_offset = 0;
    ir_led_hole_d = 4.5;
    ir_receiver_hole_d = 3.0;
    ir_led_hole_depth = 10;

    ir_ring_d = 8.8;
    ir_ring_depth = 1.4;

    ir_lock_screw_d = 2.2;

    ir_led_hole_x = ir_center_x + ir_led_x_offset;
    ir_led_hole_z = ir_center_z + ir_led_z_offset;

    hinge_z = 4;

    hinge_diameter = 6;
    door_inner_radius = 60;
    door_thickness = 3;
    hinge_radius = door_inner_radius + door_thickness + hinge_diameter/2 - 1;
    
    hinge_out_offset = 0.8;

    washer_pocket_d = 7.8;
    washer_depth = 1.8;
    washer_gap = 1.5;
    washer_holder_t = 2.9;
    washer_holder_z = 35.7;
    washer_holder_h = 9.6;
    washer_holder_w = 2*washer_pocket_d + washer_gap;
    washer_holder_wall_overlap = 0.7;
    washer_bottom_wall = 1;
    washer_side_wall = 1;

    screen_pcb_w = 44.5;
    screen_pcb_h = 37;
    screen_flat_y_start = -27.5;
    screen_pcb_y_center = screen_flat_y_start + screen_pcb_w/2;
    screen_pcb_z_center = outer_wall + 5.75 + screen_pcb_h/2;

    screen_window_w = 44.5;
    screen_window_h = 28;

    screen_screw_d = 3;
    screen_screw_y = screen_pcb_w/2 - 2.5;
    screen_screw_z = screen_pcb_h/2 - 2.5;
    
    // INNER FILL STRIPS SETTINGS

    fill1_x = -dia/2 + 5;
    fill1_y = chute_y_pos - chute_w/2 - 0.1;
    fill1_z = outer_wall - 0.2;
    fill1_wx = 1.4;
    fill1_wy = 1.2;
    fill1_h = 32;

    fill2_x = -dia/2 + 0.9;
    fill2_y = chute_y_pos + chute_w/2 - 1;
    fill2_z = outer_wall - 0.4;
    fill2_wx = 1.4;
    fill2_wy = 1.2;
    fill2_h = 34;

    module ir_cutout_side_1() {
        rotate([0, 0, chute_rotation])
            translate([
                ir_center_x,
                chute_y_pos + chute_w/2 - inner_wall + receiver_side_wall + ir_module_w/2 + 0.5,
                ir_center_z
            ])
                cube([
                    ir_module_len + 1.6,
                    ir_module_w + 0.2,
                    ir_module_h + 0.4
                ], center = true);
    }

    module ir_cutout_side_2() {
        side2_extra_y = 1.2;

        rotate([0, 0, chute_rotation])
            translate([
                ir_center_x,
                chute_y_pos - chute_w/2 - ir_module_w/2 - side2_extra_y/2,
                ir_center_z
            ])
                cube([
                    ir_module_len + 2.6,
                    ir_module_w + side2_extra_y,
                    ir_module_h + 1.0
                ], center = true);
    }

    module ir_led_holes() {
        rotate([0, 0, chute_rotation]) {

            // Receiver side - narrow tunnel through thickened wall
            translate([
                ir_led_hole_x,
                chute_y_pos + chute_w/2 - inner_wall + receiver_side_wall/2,
                ir_led_hole_z
            ])
                rotate([90, 0, 0])
                    cylinder(
                        h = receiver_side_wall + 4,
                        d = ir_receiver_hole_d,
                        center = true
                    );

            // Receiver side - circular recessed pocket on the OUTER face
            // This is a subtraction, not an added bump.
            translate([
                ir_led_hole_x,
                chute_y_pos + chute_w/2 - inner_wall + receiver_side_wall - ir_ring_depth/2,
                ir_led_hole_z
            ])
                rotate([90, 0, 0])
                    cylinder(h = ir_ring_depth, d = ir_ring_d, center = true);

            translate([
                ir_led_hole_x,
                chute_y_pos - chute_w/2,
                ir_led_hole_z
            ])
                rotate([90, 0, 0])
                    cylinder(h = ir_led_hole_depth, d = ir_led_hole_d, center = true);

            translate([
                ir_led_hole_x,
                chute_y_pos - chute_w/2 + ir_ring_depth/2,
                ir_led_hole_z
            ])
                rotate([90, 0, 0])
                    cylinder(h = ir_ring_depth, d = ir_ring_d, center = true);
        }
    }

module ir_lock_screw_holes() {
    rotate([0, 0, chute_rotation]) {

        // Right IR - side stopper screw
        translate([
            ir_center_x + 2,
            chute_y_pos - chute_w/2 - ir_module_w - 1.3,
            -1
        ])
            cylinder(h = 14, d = ir_lock_screw_d);

        // Right IR - bottom stopper screw
        translate([
            ir_center_x + ir_module_len/2 + 1.3,
            chute_y_pos - chute_w/2 - ir_module_w/2,
            -1
        ])
            cylinder(h = outer_wall + 3, d = ir_lock_screw_d);


        // Left IR - side stopper screw
        translate([
            ir_center_x + 2,
            chute_y_pos + chute_w/2 - inner_wall + receiver_side_wall + ir_module_w + 1.3,
            -1
        ])
            cylinder(h = 14, d = ir_lock_screw_d);

        // Left IR - upper stopper screw
        translate([
            ir_center_x - ir_module_len/2 - 1.3,
            chute_y_pos + chute_w/2 - inner_wall + receiver_side_wall + ir_module_w/2,
            -1
        ])
            cylinder(h = outer_wall + 3, d = ir_lock_screw_d);

        // Left IR - bottom stopper screw
        translate([
            ir_center_x + ir_module_len/2 + 1.3,
            chute_y_pos + chute_w/2 - inner_wall + receiver_side_wall + ir_module_w/2,
            -1
        ])
            cylinder(h = outer_wall + 3, d = ir_lock_screw_d);
    }
}

    difference() {
        union() {

            difference() {
                cylinder(h = height, d = dia);

                translate([0, 0, outer_wall])
                    cylinder(h = height + 1, d = dia - outer_wall*2);

                rotate([0, 0, 30])
                    translate([dia/2 - outer_wall - 6, -27.5, -1])
                        cube([30, 55, height + 2]);

                rotate([0, 0, chute_rotation])
                    translate([-dia/2 - 5, chute_y_pos - chute_w/2, outer_wall])
                        cube([chute_d + 5, chute_w, 32]); 
            }

            rotate([0, 0, 30])
                translate([dia/2 - outer_wall - 6, -27.5, 0])
                    cube([outer_wall, 55, height]);

            rotate([0, 0, chute_rotation]) {

                translate([-hinge_radius - 3.5 - hinge_out_offset, chute_y_pos - 27 - 3, 0])
                    cube([26, 6, 10]);

                translate([-hinge_radius - 3.5 - hinge_out_offset, chute_y_pos + 27 - 3, 0])
                    cube([18, 6, 10]);
            }

            rotate([0, 0, chute_rotation]) {
                translate([
                    -dia/2 + outer_wall - washer_holder_wall_overlap,
                    chute_y_pos - washer_holder_w/2,
                    washer_holder_z
                ])
                    cube([
                        washer_holder_t + washer_holder_wall_overlap +0.5,
                        washer_holder_w,
                        washer_holder_h
                    ]);
            }

            // INNER FILL STRIPS
            rotate([0, 0, chute_rotation]) {
                translate([fill1_x, fill1_y, fill1_z])
                    cube([fill1_wx, fill1_wy, fill1_h]);

                translate([fill2_x, fill2_y, fill2_z])
                    cube([fill2_wx, fill2_wy, fill2_h]);
            }

            rotate([0, 0, chute_rotation])
            intersection() {

                cylinder(h = height, d = dia);

                difference() {

                    union() {

                        translate([-dia/2, chute_y_pos - chute_w/2, outer_wall]) {

                            color("lime")
                            translate([0.8, inner_wall, 0])
                                cube([
                                    chute_d - inner_wall - 0.8,
                                    chute_w - 2*inner_wall,
                                    chute_floor_raise
                                ]);

                            color("blue")
                            hull() {
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

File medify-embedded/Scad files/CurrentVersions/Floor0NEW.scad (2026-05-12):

// Medify - Floor 0: Cylindrical Base
$fn = 100;

bb_l_real = 83.5;
bb_w_real = 54.5;

dia = 120;
height = 45;
wall = 3;

fan_size = 30;
fan_screw_dist = 24;
fan_mount_size = 36;
fan_mount_t = 3;
fan_mount_overlap = 1;
fan_z = wall + 22;

fan_slot_w = 3.3;
fan_slot_h = 23.5;
fan_slot_positions = [-8, -4, 0, 4, 8];

pillar_angles = [150, 330];

difference() {
    union() {
        cylinder(h = height, d = dia);

        for(a = pillar_angles) {
            rotate([0, 0, a])
            translate([dia/2 + 3, 0, 0])
            cylinder(h = height, d = 10);
        }
    }

    translate([0, 0, wall])
    cylinder(h = height, d = dia - wall*2);

    for(a = pillar_angles) {
        rotate([0, 0, a])
        translate([dia/2 + 3, 0, 0]) {
            translate([0, 0, -1])
            cylinder(h = height + 2, d = 3.8);

            translate([0, 0, -1])
            rotate([0, 0, 30])
            cylinder(h = 5, r = 3.2, $fn = 6);
        }
    }

    // Air slots through the curved wall
    for (i = fan_slot_positions) {
        translate([i, -dia/2 + wall/2, fan_z])
        cube([fan_slot_w, wall + 4, fan_slot_h], center=true);
    }

    // Oval screw holes through the curved wall
    for (x = [-fan_screw_dist/2, fan_screw_dist/2],
         z = [fan_z - fan_screw_dist/2, fan_z + fan_screw_dist/2]) {
        translate([x, -dia/2 + wall/2, z])
        rotate([90, 0, 0])
        hull() {
            translate([0, 0, -2])
            cylinder(h = wall + 6, r = 1.7, center=true);

            translate([0, 0, 2])
            cylinder(h = wall + 6, r = 1.7, center=true);
        }
    }

    // Cable opening
    translate([0, dia/2, wall + 12])
    rotate([90, 0, 0])
    hull() {
        translate([-5, 0, 0])
        cylinder(h = 20, r = 4, center=true);

        translate([5, 0, 0])
        cylinder(h = 20, r = 4, center=true);
    }
}

// Breadboard frame
frame_h = 3;
frame_wall = 2;
clearance = 1.5;

inner_l = bb_l_real + 2*clearance;
inner_w = bb_w_real + 2*clearance;

outer_l = inner_l + 2*frame_wall;
outer_w = inner_w + 2*frame_wall;

translate([0, 0, wall]) {
    difference() {
        translate([-outer_l/2, -outer_w/2, 0])
        cube([outer_l, outer_w, frame_h]);

        translate([-inner_l/2, -inner_w/2, -1])
        cube([inner_l, inner_w, frame_h + 2]);
    }
}

// Internal flat fan mount
difference() {
    translate([
        -fan_mount_size/2,
        -dia/2 + wall - fan_mount_overlap,
        fan_z - fan_mount_size/2
    ])
    cube([
        fan_mount_size,
        fan_mount_t + fan_mount_overlap,
        fan_mount_size
    ]);

    // Air slots through the flat mount
    for (i = fan_slot_positions) {
        translate([
            i,
            -dia/2 + wall + fan_mount_t/2,
            fan_z
        ])
        cube([fan_slot_w, fan_mount_t + 4, fan_slot_h], center=true);
    }

    // Oval screw holes in the flat mount
    for (x = [-fan_screw_dist/2, fan_screw_dist/2],
         z = [fan_z - fan_screw_dist/2, fan_z + fan_screw_dist/2]) {
        translate([
            x,
            -dia/2 + wall + fan_mount_t/2,
            z
        ])
        rotate([90, 0, 0])
        hull() {
            translate([0, 0, -2])
            cylinder(h = fan_mount_t + 6, r = 1.7, center=true);

            translate([0, 0, 2])
            cylinder(h = fan_mount_t + 6, r = 1.7, center=true);
        }
    }
}

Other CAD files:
medify-embedded/Scad files/CurrentVersions/STL files/Floo11_5FINAL.stl
medify-embedded/Scad files/CurrentVersions/STL files/Floor1_4FINAL.stl
medify-embedded/Scad files/OldVersions/STL files/Floor2Base.stl
medify-embedded/Scad files/OldVersions/STL files/Floor2Base4FINAL.stl
medify-embedded/Scad files/CurrentVersions/Floor1_4FINAL.scad
medify-embedded/Scad files/CurrentVersions/Floor1_6FINAL.scad
medify-embedded/Scad files/CurrentVersions/Floor2Base4FINAL.scad
medify-embedded/Scad files/CurrentVersions/MagnetPocketCover1.scad
medify-embedded/Scad files/CurrentVersions/MagnetPocketCover2.scad
medify-embedded/Scad files/CurrentVersions/MagnetPocketCover3.scad
medify-embedded/Scad files/CurrentVersions/TempDoor.scad
medify-embedded/Scad files/CurrentVersions/TempFourFloor2WindmillFINAL.scad
medify-embedded/Scad files/CurrentVersions/UpperCover.scad
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

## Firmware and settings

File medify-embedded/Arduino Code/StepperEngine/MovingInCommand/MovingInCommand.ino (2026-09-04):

// Requires two extra libraries (Arduino IDE Library Manager):
//   - "WebSockets" by Markus Sattler / Links2004   (device -> backend WebSocket client)
//   - "ArduinoJson" by Benoit Blanchon              (v6 API used below)
//
// The device no longer runs an HTTP server. It dials OUT to the backend and
// keeps that connection open, so it works from any network the backend is
// reachable from — no fixed LAN IP for the app to hardcode.
//
// This file combines three previously-separate, individually-tested sketches:
//   - StepperEngine/test_FullCycle.ino  -> motor control (stepMotor/powerOffMotor/moveOneSlot, unchanged)
//   - IR/IR_Check1.ino                  -> IR sensor pin/read approach (unchanged), debounce loop is new
//   - Button/sketch_aug21a.ino          -> button pin/read approach (unchanged), edge-detection is new
// Only the communication layer (WiFiServer -> WebSocket client) is new.

#include <WiFiNINA.h>
#include <WebSocketsClient.h>
#include <ArduinoJson.h>
#include <string.h>

// ── Motor pins ──────────────────────────────────────────────────
#define IN1 6
#define IN2 7
#define IN3 8
#define IN4 9

// ── IR sensor pin (watches the intake compartment) ─────────────
// Confirmed against the real sensor: HIGH/1 = compartment empty, LOW/0 = pill present.
#define IR_PIN 5

// ── Button pin (manual approval trigger — alternative to the app) ─
// INPUT_PULLUP, matching Button/sketch_aug21a.ino: LOW = pressed.
#define BUTTON_PIN 4

int steps[8][4] = {
  {1,0,0,0}, {1,1,0,0}, {0,1,0,0}, {0,1,1,0},
  {0,0,1,0}, {0,0,1,1}, {0,0,0,1}, {1,0,0,1}
};

const int TOTAL_SLOTS = 13;
const int STEPS_PER_REV = 4096;
int currentSlot = 0;
int stepIndex = 0;

// ── Wi-Fi ───────────────────────────────────────────────────────
char ssid[] = "NettaS";
char pass[] = "12345678";

// ── Backend / device identity ──────────────────────────────────
// Must match a row in the backend's `devices` table (see
// medify-backend V16__create_devices_table.sql for the seeded dev device).
// deviceId/token are provisioned once per physical unit — do not commit a
// real device's token to a shared repo.
// BACKEND_HOST is the AWS ALB's DNS name (port 80 -- the ALB listener, which
// forwards to the container's 8080 internally; the container port itself
// isn't reachable directly from outside the ECS security group). Plain HTTP,
// not HTTPS/WSS -- no TLS in front of this Learner Lab deployment yet.
const char* BACKEND_HOST = "medify-alb-14738975.us-east-1.elb.amazonaws.com";
const uint16_t BACKEND_PORT = 80;
const char* DEVICE_ID = "pillbox-01";
const char* DEVICE_TOKEN = "25e229c56d9448b8a74de53d66649cf112671da4a2ac5037d47a78fbcb6af42c";

WebSocketsClient webSocket;
bool wsConnected = false;
bool wsClientStarted = false;         // has connectWebSocket() ever been called (WiFi reached WL_CONNECTED at least once)
// Whether this connection has received the backend's authoritative currentSlot yet. The backend
// is the source of truth for physical wheel position (survives reboots; this device's own
// currentSlot below does not) -- no command:dispense may execute until this is true. Reset to
// false on every disconnect so a reconnect (not just a power cycle) re-syncs before dispatching
// resumes; the backend re-sends "sync" on every new connection regardless of cause.
bool slotSynced = false;
unsigned long lastWifiAttemptMs = 0;
const unsigned long WIFI_RETRY_INTERVAL_MS = 5000;

unsigned long lastHeartbeatMs = 0;
const unsigned long HEARTBEAT_INTERVAL_MS = 20000;

// ── Intake-watch state ──────────────────────────────────────────
// After a dispense, loop() polls the IR sensor until it confirms the
// compartment emptied — there is no timeout here on purpose: the intake
// just stays DISPENSED on the backend until this fires, however long it takes.
//
// Time-based, using millis() — not a loop-iteration counter, since loop()
// iterations aren't a fixed/meaningful unit of time:
//   moveOneSlot() done -> ignore the sensor for IR_SETTLE_MS (pill hasn't
//   necessarily landed yet) -> then require IR_CONFIRM_DURATION_MS of
//   *continuous* HIGH (empty) before confirming. Any LOW read during that
//   window resets the continuous-empty timer back to zero.
bool watchingIntake = false;
long watchingIntakeId = -1;
unsigned long dispensedAtMs = 0;          // millis() when moveOneSlot() finished for this intake
bool irSettled = false;                   // whether IR_SETTLE_MS has elapsed since dispensedAtMs
unsigned long emptySinceMs = 0;           // millis() the current continuous-HIGH streak started (0 = not counting)
const unsigned long IR_SETTLE_MS = 1000;         // ignore the sensor for 1s right after dispensing
const unsigned long IR_CONFIRM_DURATION_MS = 10000; // must read continuously empty for 10s to confirm

unsigned long lastIrPrintMs = 0;
const unsigned long IR_SERIAL_PRINT_INTERVAL_MS = 150; // throttle Serial output while watching

// ── Button debounce state ────────────────────────────────────────
// True debounce, not just a rate limiter: a raw reading must hold steady for
// BUTTON_DEBOUNCE_MS before it's trusted as the new stable state. A press
// fires exactly once (buttonEventArmed latches on press) and only re-arms
// once a stable RELEASE has been confirmed — holding the button, or any
// contact bounce/chatter while held, cannot retrigger it.
int buttonStableState = HIGH;
int buttonLastRawState = HIGH;
unsigned long buttonLastChangeMs = 0;
bool buttonEventArmed = true;
const unsigned long BUTTON_DEBOUNCE_MS = 300;

// Independent cooldown on actually SENDING button_pressed — even genuinely
// distinct repeated presses (not bounce) shouldn't spam the backend/app
// when nothing has had time to change. Configurable in one place, not a
// magic number buried in the logic.
unsigned long lastButtonSentMs = 0;
const unsigned long BUTTON_PRESS_COOLDOWN_MS = 5000;

void setup() {
  pinMode(IN1, OUTPUT); pinMode(IN2, OUTPUT);
  pinMode(IN3, OUTPUT); pinMode(IN4, OUTPUT);
  pinMode(IR_PIN, INPUT);
  pinMode(BUTTON_PIN, INPUT_PULLUP);
  Serial.begin(9600);

  // Deliberately does NOT block here waiting for WiFi — pollButton() must start working from the
  // very first loop() iteration regardless of network state. The first connection attempt happens
  // on the first loop() tick via maybeConnectWiFi(), the same non-blocking path used for every
  // reconnect after that.
}

void loop() {
  if (WiFi.status() != WL_CONNECTED) {
    wsConnected = false;
    maybeConnectWiFi(); // rate-limited single attempt — never blocks loop() for long, unlike the old while(){delay(5000);} retry
  } else {
    if (!wsClientStarted) {
      connectWebSocket(); // WiFi is up and this hasn't run yet — start the WS client exactly once
      wsClientStarted = true;
    }
    webSocket.loop(); // also drives automatic reconnect (see setReconnectInterval below)
  }

  if (wsConnected) {
    sendHeartbeatIfDue();
  }

  if (watchingIntake) {
    pollIrSensor();
  }

  pollButton(); // must run every iteration — a physical press has to be detectable locally no matter what state WiFi/WebSocket are in
}

// ── Wi-Fi / WebSocket connection management ─────────────────────
// Non-blocking on purpose. The previous connectWiFi() was `while (not connected) { WiFi.begin();
// delay(5000); }`, called both in setup() and again in loop() whenever WiFi dropped — if the
// network was ever unreachable (out of range, wrong SSID/password, router down), that while loop
// never returned, so loop() — and therefore pollButton() — never ran at all. That's why a real
// press produced zero Serial output: the button-polling code was simply never being reached.
// (wsClientStarted/lastWifiAttemptMs/WIFI_RETRY_INTERVAL_MS are declared near the top of the file,
// alongside wsConnected, since they're read from loop() before this point in the file — plain
// globals need top-to-bottom declaration order; only functions get auto-forward-declared.)

void maybeConnectWiFi() {
  unsigned long now = millis();
  if (now - lastWifiAttemptMs < WIFI_RETRY_INTERVAL_MS) return; // rate limit only — no delay()/blocking wait
  lastWifiAttemptMs = now;

  Serial.print("Connecting to WiFi: ");
  Serial.println(ssid);
  WiFi.begin(ssid, pass); // one attempt; if it fails, loop() keeps running and this retries in ~5s

  if (WiFi.status() == WL_CONNECTED) {
    Serial.print("WiFi connected, IP: ");
    Serial.println(WiFi.localIP());
    // WS client startup happens in loop() itself (not here) so it's triggered on any iteration
    // where WiFi turns out to be connected, not only immediately after a WiFi.begin() call returns.
  }
}

void connectWebSocket() {
  String path = String("/ws/device?deviceId=") + DEVICE_ID + "&token=" + DEVICE_TOKEN;

  Serial.print("Connecting to backend: ws://");
  Serial.print(BACKEND_HOST);
  Serial.print(":");
  Serial.print(BACKEND_PORT);
  Serial.println(path);

  webSocket.begin(BACKEND_HOST, BACKEND_PORT, path.c_str());
  webSocket.onEvent(onWsEvent);
  webSocket.setReconnectInterval(5000); // library handles retry/backoff internally from here on
}

void sendHeartbeatIfDue() {
  unsigned long now = millis();
  if (now - lastHeartbeatMs < HEARTBEAT_INTERVAL_MS) return;
  lastHeartbeatMs = now;

  StaticJsonDocument<128> doc;
  doc["type"] = "heartbeat";
  doc["deviceId"] = DEVICE_ID;
  sendJson(doc);
}

// ── Incoming messages from the backend ──────────────────────────
// The ONLY place that calls performDispense() — the backend alone decides whether/when to
// dispense (see IntakeOrchestrationService server-side), whether that decision was triggered by
// the app's Take Now or by this device's own button_pressed event below. The device never picks
// an intake and never calls performDispense() on its own initiative; it only executes exactly the
// command:dispense messages the backend sends, here.

void onWsEvent(WStype_t type, uint8_t* payload, size_t length) {
  switch (type) {
    case WStype_CONNECTED:
      wsConnected = true;
      Serial.println("WebSocket connected");
      break;

    case WStype_DISCONNECTED:
      wsConnected = false;
      slotSynced = false; // must re-sync currentSlot from the backend on the next connection
      Serial.println("WebSocket disconnected");
      break;

    case WStype_TEXT:
      handleWsMessage(payload, length);
      break;

    default:
      break; // WStype_PING/PONG/ERROR/etc. — nothing to do
  }
}

void handleWsMessage(uint8_t* payload, size_t length) {
  StaticJsonDocument<256> doc;
  DeserializationError err = deserializeJson(doc, payload, length);
  if (err) {
    Serial.print("Bad JSON from backend: ");
    Serial.println(err.c_str());
    return;
  }

  const char* type = doc["type"];
  if (type == nullptr) return;

  if (strcmp(type, "sync") == 0) {
    // The backend's authoritative, persisted physical position -- overrides whatever this
    // device's own currentSlot currently is (0 on a fresh boot; whatever it was in memory on a
    // mere reconnect). Sent once per connection, right after the WebSocket handshake completes.
    currentSlot = doc["currentSlot"];
    slotSynced = true;
    Serial.print("Synced currentSlot from backend: ");
    Serial.println(currentSlot);
    sendSyncAck();
    return;
  }

  if (strcmp(type, "command") != 0) return;

  const char* command = doc["command"];
  if (command == nullptr || strcmp(command, "dispense") != 0) return;

  const char* commandId = doc["commandId"];
  long intakeId = doc["intakeId"];

  // Must not execute (or even ack) a dispense before currentSlot has been synced from the
  // backend. The backend already gates dispatch on this too (DeviceConnectionAdapter refuses to
  // send command:dispense until it sees this device's sync_ack), so this should never actually be
  // reached in normal operation -- it's a deliberate second line of defense, since firmware should
  // never trust the network to enforce ordering by itself. Silently not acking here surfaces as
  // the backend's existing 5s ack-timeout instead of risking a move from an unknown position.
  if (!slotSynced) {
    Serial.println("Ignoring command:dispense -- currentSlot not yet synced from backend");
    return;
  }

  sendAck(commandId);
  performDispense(commandId, intakeId);
}

void performDispense(const char* commandId, long intakeId) {
  moveOneSlot();
  sendDispensedEvent(commandId, intakeId);

  // Motor's done — start watching this intake, but don't trust the IR
  // sensor yet (see pollIrSensor's settle-period handling below).
  watchingIntake = true;
  watchingIntakeId = intakeId;
  dispensedAtMs = millis();
  irSettled = false;
  emptySinceMs = 0;
}

void pollIrSensor() {
  unsigned long now = millis();

  // Don't trust the sensor until the settle period has elapsed — the pill
  // may not have physically landed in front of it yet.
  if (!irSettled) {
    if (now - dispensedAtMs < IR_SETTLE_MS) return;
    irSettled = true;
    emptySinceMs = 0;
    lastIrPrintMs = 0;
  }

  int state = digitalRead(IR_PIN);

  if (now - lastIrPrintMs >= IR_SERIAL_PRINT_INTERVAL_MS) {
    lastIrPrintMs = now;
    Serial.println(state == HIGH ? "IR: 1 - EMPTY" : "IR: 0 - PILL PRESENT");
  }

  if (state == HIGH) {
    if (emptySinceMs == 0) {
      emptySinceMs = now; // start of a new continuous-empty window
    } else if (now - emptySinceMs >= IR_CONFIRM_DURATION_MS) {
      sendIntakeConfirmedEvent(watchingIntakeId);
      watchingIntake = false;
      watchingIntakeId = -1;
      emptySinceMs = 0;
      irSettled = false;
    }
  } else {
    emptySinceMs = 0; // pill still present (or present again) — reset the 10s window
  }
}

// ── Physical button ───────────────────────────────────────────────
// Purely a notification to the backend — this NEVER calls performDispense() directly and never
// decides which intake is eligible. The backend (IntakeOrchestrationService.requestIntakeNow)
// makes that decision entirely server-side and, if a dose is eligible, sends this device a normal
// command:dispense message — the exact same message it would send for an app-initiated dispense.
// The mobile app is NOT involved in and NOT required for this flow.
//
// Debounce/cooldown state machine is unchanged from before this fix (it was not the bug — see the
// Wi-Fi/WebSocket section above for the actual root cause). What's new here is Serial visibility
// into each stage, requested for bench testing:
//   raw edge          -> every physical transition of the pin, before debounce
//   accepted/ignored   -> the debounced, confirmed press, and why it was or wasn't acted on
//   WebSocket status   -> whether the resulting event actually got sent
void pollButton() {
  int rawState = digitalRead(BUTTON_PIN);
  unsigned long now = millis();

  if (rawState != buttonLastRawState) {
    Serial.println(rawState == LOW ? "BUTTON: raw edge -> LOW (physical press detected)"
                                    : "BUTTON: raw edge -> HIGH (physical release detected)");
    buttonLastRawState = rawState;
    buttonLastChangeMs = now;
  }

  // Only trust the raw reading once it's held steady for the full debounce window.
  if ((now - buttonLastChangeMs) < BUTTON_DEBOUNCE_MS) return;
  if (buttonStableState == buttonLastRawState) return; // no confirmed change

  buttonStableState = buttonLastRawState;

  if (buttonStableState == LOW) { // confirmed press (INPUT_PULLUP: LOW = pressed)
    Serial.println("BUTTON: PRESSED (accepted after debounce)");
    if (buttonEventArmed) {
      buttonEventArmed = false; // re-arms only on a confirmed release, below
      maybeSendButtonPressedEvent();
    }
  } else {
    Serial.println("BUTTON: RELEASED");
    buttonEventArmed = true;
  }
}

void maybeSendButtonPressedEvent() {
  unsigned long now = millis();
  unsigned long sinceLast = now - lastButtonSentMs;
  if (sinceLast < BUTTON_PRESS_COOLDOWN_MS) {
    Serial.print("BUTTON: press ignored — cooldown active, ");
    Serial.print(BUTTON_PRESS_COOLDOWN_MS - sinceLast);
    Serial.println("ms remaining");
    return;
  }
  lastButtonSentMs = now;
  sendButtonPressedEvent();
}

void sendButtonPressedEvent() {
  if (!wsConnected) {
    Serial.println("BUTTON: press accepted but NOT sent — WebSocket disconnected");
    return;
  }

  StaticJsonDocument<96> doc;
  doc["type"] = "event";
  doc["event"] = "button_pressed";
  sendJson(doc);
  Serial.println("BUTTON_PRESSED SENT");
}

// ── Outgoing messages to the backend ────────────────────────────

void sendAck(const char* commandId) {
  StaticJsonDocument<128> doc;
  doc["type"] = "ack";
  doc["commandId"] = commandId;
  sendJson(doc);
}

void sendDispensedEvent(const char* commandId, long intakeId) {
  // currentSlot already reflects the post-move position here -- moveOneSlot() (called just before
  // this, in performDispense) increments it before returning. This is the only place the backend
  // learns the device's new position; DeviceWebSocketHandler persists it into devices.current_slot.
  StaticJsonDocument<192> doc;
  doc["type"] = "event";
  doc["event"] = "dispensed";
  doc["commandId"] = commandId;
  doc["intakeId"] = intakeId;
  doc["currentSlot"] = currentSlot;
  sendJson(doc);
}

void sendSyncAck() {
  StaticJsonDocument<96> doc;
  doc["type"] = "sync_ack";
  doc["currentSlot"] = currentSlot;
  sendJson(doc);
}

void sendIntakeConfirmedEvent(long intakeId) {
  StaticJsonDocument<128> doc;
  doc["type"] = "event";
  doc["event"] = "intake_confirmed";
  doc["intakeId"] = intakeId;
  sendJson(doc);
}

void sendJson(JsonDocument& doc) {
  String payload;
  serializeJson(doc, payload);
  webSocket.sendTXT(payload);
}

// ── Motor control (unchanged from test_FullCycle.ino / the original sketch) ──

void stepMotor(int step) {
  digitalWrite(IN1, steps[step][0]);
  digitalWrite(IN2, steps[step][1]);
  digitalWrite(IN3, steps[step][2]);
  digitalWrite(IN4, steps[step][3]);
}

void powerOffMotor() {
  digitalWrite(IN1, LOW); digitalWrite(IN2, LOW);
  digitalWrite(IN3, LOW); digitalWrite(IN4, LOW);
}

void moveOneSlot() {
  long currentPos = (long)currentSlot * STEPS_PER_REV / TOTAL_SLOTS;
  long nextPos = (long)(currentSlot + 1) * STEPS_PER_REV / TOTAL_SLOTS;
  int stepsToMove = nextPos - currentPos;

  for (int i = 0; i < stepsToMove; i++) {
    stepMotor(stepIndex);
    stepIndex++;
    if (stepIndex > 7) stepIndex = 0;
    delay(3);
  }
  powerOffMotor();
  currentSlot = (currentSlot + 1) % TOTAL_SLOTS;
}

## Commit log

2026-05-28 Adding new versions of scad files
    [Floo11_5FINAL.scad, Floo11_5FINAL.stl, Floor1_4FINAL.scad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]
2026-06-02 Update notification flow, intake logic, Flutter UI, and Arduino code
2026-06-02 Update all MD files to reflect current code state
2026-06-03 Add CORS header to Arduino HTTP response
2026-06-04 Update Arduino delay, presentation, add video demo and IR code
2026-07-26 Add edit medicines screen, disable/delete medicine, and UI improvements
    - Backend: add PUT/DELETE/PATCH endpoints for medicine management (disable,
    enable, disable-until, clear-until), V8 migration for disabled_until column,
    fix @PathVariable names, add -parameters compiler flag, Jackson date config
    - Flutter: new two-screen Edit Medicines flow (list + detail with save/delete/
    disable-until date picker), filter disabled medicines from home and caregiver
    schedules, add InstructionOption.none, remove other from timing dropdown,
    required time window validation, free-text field for other instruction,
    add Medify logo to all AppBars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
2026-07-26 Add fill box guide feature and merge coworker FCM changes
    - Box refill guide: 13-slot carousel guide with circular slot order,
    fill/unfill tracking, progress bar, dispensed-slot refill support
    - Backend: box_refill_sessions + box_slot_fills tables, BoxRefillService,
    BoxRefillController, intake count query for current slot inference
    - Flutter: FillBoxGuideScreen, sidebar entry, logo size increase to 56px
    - Merge: kept coworker FCM token registration alongside box refill methods
2026-08-13 Dockerize backend and externalize config
    [Floor1_6FINAL.stl]
2026-08-13 Add Firebase Auth patient/caregiver separation and per-medicine box-fill wizard
    Replaces hardcoded patient/caregiver user IDs with real Firebase-authenticated
    accounts (email/password), auto-linking caregivers to the single patient via
    caregiver_links. Also reworks the fill-pill-box flow from a day/timing-grouped
    checklist into a per-medicine, elderly-friendly step-through wizard shared by
    both roles, with live polling so fills sync across sessions.
2026-08-13 Split user names, add email lookup, and improve registration flow
    Replace User.username with firstName/lastName fields across backend
    (domain, data, API layers) with a Flyway migration, and add
    findByEmail to the repository port for auth lookups. Update the
    Flutter registration screen and API service to match, add a small
    app logger util, and surface backend error messages to the client.
2026-08-22 Arduino Tests
2026-08-22 Relay app-device communication through backend via persistent WebSocket
    The app no longer talks to the pill box by hardcoded IP. The device now
    holds a persistent, authenticated WebSocket connection to the backend
    (/ws/device), and the app dispenses via POST /api/intakes/{id}/dispense,
    which the backend relays over that socket. This makes cross-network
    operation possible and adds device identity, auth, and online/offline
    tracking, while keeping the app as the sole decision-maker — the backend
    only relays, persists, and manages the connection.
    Also splits the intake status flow so TAKEN is only set once the device's
    IR sensor confirms the compartment is empty, not on a successful motor
    mov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
2026-08-22 Relay physical button presses to the app as a distinct notification type
    The pill box's manual button is a second way to start the same intake
    flow as the app, not a separate path. The device just sends
    event:button_pressed with no intake id; the backend relays it through
    the existing GET /api/notification poll (now carrying an explicit
    "type" field) and logs it as NotificationType.BUTTON_PRESSED. The
    backend does not pick an intake, approve anything, or dispatch a
    dispense command for this — that decision stays with the app.
    Also fixes a latent NPE risk in NotificationAdapter.sendPushNotification:
    putData("timing", timing) would throw if timing were ever null, which
    this button-pressed p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
2026-08-22 Replace device HTTP server with an outbound WebSocket client
    Combines the previously-separate, individually-tested motor
    (test_FullCycle.ino), IR sensor (IR_Check1.ino), and button
    (sketch_aug21a.ino) logic into the device's main firmware, reusing
    each verbatim. The only rewritten layer is communication: the device
    now dials out to the backend over ws://<host>/ws/device instead of
    running a WiFiServer, so it works without the app needing a hardcoded
    device IP.
    performDispense() is the single path that moves the motor — it only
    ever runs in response to a command:dispense message from the backend.
    The physical button never triggers it directly: pressing it just sends
    a button_pressed event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
    [MovingInCommand.ino]
2026-08-22 Add INCOMPLETE intake status for dispensed-but-unconfirmed pills
    Distinguishes two ways an intake can go unresolved: MISSED (never even
    approved/dispensed before its reminder window expired) vs. INCOMPLETE
    (pills were dispensed but the IR sensor never confirmed the compartment
    emptied). These are judged on separate clocks on purpose — MISSED is
    relative to the original reminder window, INCOMPLETE is relative to
    the actual DISPENSED timestamp (new intakes.dispensed_time column), so
    a late approval doesn't unfairly shrink the IR confirmation window.
    The grace period (30 min default) lives as a single externalized
    config value, medify.intake.incomplete-grace-minutes, not a magic
    number in th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
2026-08-22 Route the app's dispense flow and status display through the backend relay
    Covers the full Flutter side of the device-websocket-relay work to date:
    - api_service.dart: removed embeddedBaseUrl/dispenseFromDevice() (the
    app never talks to the device directly) and releaseIntake() (the
    backend route it hit no longer exists). Added dispenseIntake() and
    getIntake() against the new backend endpoints.
    - home_screen.dart: _handleConfirmIntake now calls dispenseIntake then
    polls getIntake every 3s (~2min cap, UI-only — never marks anything
    TAKEN/MISSED/INCOMPLETE itself) waiting for the backend to report
    TAKEN, which only happens once the device's IR sensor confirms.
    Added _handleButt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
2026-08-22 Add configurable intake reminder times and caregiver management
    Patients can now change the daily MORNING/NOON/EVENING reminder times
    from a new Settings screen instead of relying on hardcoded cron
    expressions, and can add/remove caregivers by email from the same
    screen. The scheduler now uses dynamic per-timing triggers backed by
    a settings table, re-queuing all three on save so changes take effect
    the same day. Also fixes a missing jakarta.annotation-api dependency
    and pins the backend container to Asia/Jerusalem so reminders fire at
    the intended local time instead of UTC.
2026-08-22 Swap device WebSocket client to WebSockets (Links2004) for Nano 33 IoT compatibility
    ArduinoWebsockets didn't compile on the Arduino Nano 33 IoT. Replaces
    it with WebSockets by Markus Sattler/Links2004, which does. Only the
    connection-management and message-dispatch layer changes:
    - WiFiNINA + WebSocketsClient (webSocket.begin/onEvent/loop/sendTXT)
    instead of ArduinoWebsockets' wsClient.connect/onMessage/onEvent/poll/send
    - A single WStype_t event switch (CONNECTED/DISCONNECTED/TEXT) replaces
    the separate onMessage/onEvent callbacks
    - webSocket.setReconnectInterval() replaces the hand-rolled exponential
    backoff loop — same always-keep-trying behavior, now via the
    library's own ret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
    [MovingInCommand.ino]
2026-08-22 Improve WebSocket handling and device notifications
2026-08-22 Fix physical button intake handling
2026-08-22 Semi Fix physical button
    [MovingInCommand.ino]
2026-08-23 Add early intake, missed dose handling, and backend button flow
2026-08-23 Button Bug
2026-08-23 Continue Button Bug
2026-08-23 Continue Button Bug 2
2026-09-03 Carry over missed windows, add intake history, show caregiver's patient
    - Fix getToday() to carry over a previous day's unresolved intake (MISSED/
    DISPENSED/etc.) so it stays visible until actually taken; SKIPPED stays
    excluded since it's a deliberate terminal outcome, not a pending dose.
    - Add GET /api/intakes/history: last 5 days of intake history with a
    computed outcome (taken on time / after postponed / after missed /
    missed / skipped / incomplete / in-progress) and lateness, shared by
    patient and caregiver apps via a new history screen off both sidebars.
    - Expose the linked patient's name to a caregiver via GET /api/auth/me
    and show it prominently in CaregiverScreen's app ba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
    [MovingInCommand.ino]
2026-09-04 Make backend authoritative for device slot position; redesign refill as medicine-centric with persisted per-slot contents
    Backend-authoritative currentSlot:
    - devices.current_slot persists the wheel's real position, synced to the device on every
    WebSocket connect (a fresh sync push, gated dispatch via a new NOT_SYNCED outcome) instead of
    trusting the device's own RAM-only counter, which resets to 0 on every reboot
    - devices.next_due_timing advances in lockstep with current_slot on every completed dispense
    (MORNING -> NOON -> EVENING -> MORNING), reported by the device in the same "dispensed" event
    Refill model redesign:
    - Previous model (box_slot_fills/box_refill_sessions) reset all f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
    [MovingInCommand.ino]
